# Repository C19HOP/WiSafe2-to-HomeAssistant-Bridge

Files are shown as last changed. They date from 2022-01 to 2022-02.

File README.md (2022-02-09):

# WiSafe2-to-HA Bridge readme

## Quick Links
- [Arduino Sketch](https://github.com/C19HOP/WiSafe2-to-HomeAssistant-Bridge/blob/master/Arduino/FireAngelNano.ino)
- [Enclosure](https://github.com/C19HOP/WiSafe2-to-HomeAssistant-Bridge/blob/master/Enclosure/WiSafe2-to-HA-Bridge-enclosure.stl)
- [PCB (easyEDA)](https://github.com/C19HOP/WiSafe2-to-HomeAssistant-Bridge/blob/master/PCB/WiSafe2HA-bridge-PCB.json)
- [HomeAssistant Configuration](https://github.com/C19HOP/WiSafe2-to-HomeAssistant-Bridge/tree/master/HA)

## Project Background
Like some others, I have some expired Google Nest Protects, which I wanted to replace with a cheaper / more-scalable alternative. But above all, I wanted to realise a trustworthy fire/CO alarm system, which integrates with HomeAssistant.

In pursuit of this, I initially purchased FireAngel's commercial IoT solution; The 'Connected Gateway', but after a few basic tests, I found it to be a dreadfully unreliable piece of kit. In the end, I lost all faith in the Gateway and instead, I decided to build my own bridge from a donor radio module.

## Rant about the FireAngel Pro Connected Gateway
What was so bad about the gateway?...

As part of my initial testing, I removed all the alarms from my property, ran a test, and it didn't notice! 

Specifically, when I pressed the 'test' button in the App, it took a while to time-out and then eventually reported that all my alarms were 'online'. 

Even worse, after leaving the gateway completely unplugged for almost a year, the FireAngel App still tells me that one alarm is online. It also shows some obnoxious message "Monitoring the risk to your home in real time using complex algorithms… Risk is low!?!”.

I don't know what these "complex algorithms" are, but they are certainly not "real time"! The fact that they've concluded "me and my family are safe" after being offline for 9 months is very concerning.  
I'm just glad I found this out from testing, before putting any faith in the solution.

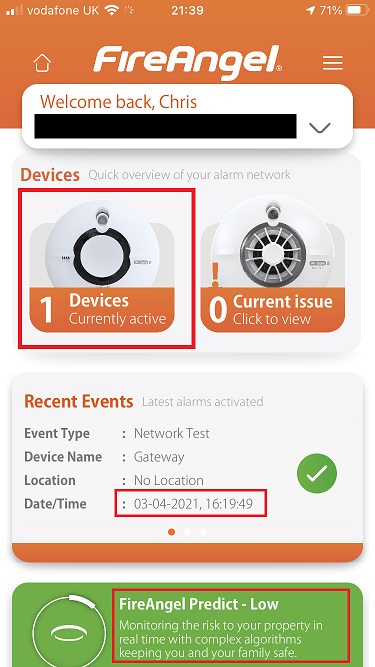
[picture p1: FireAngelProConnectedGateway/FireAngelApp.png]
App after 9 months offline


So after being bitterly disappointed with the FireAngel Gateway (and not minding if I destroyed it), my next step was to attach it to a debugger, to see exactly what it was doing (with the mindset of intercepting its comms to create a local HA integration).
I could see some JSON state changes being sent to an AWS server in Frankfurt. But I found the messages were very slow to report, and even worse was that it stopped updating locally if the internet connection went down. 

If you want to attach a serial debug logger to a Gateway yourself, then you can use a 3.3v USB-to-serial adapter, and attach GND-to-GND and TX-to-RX
 
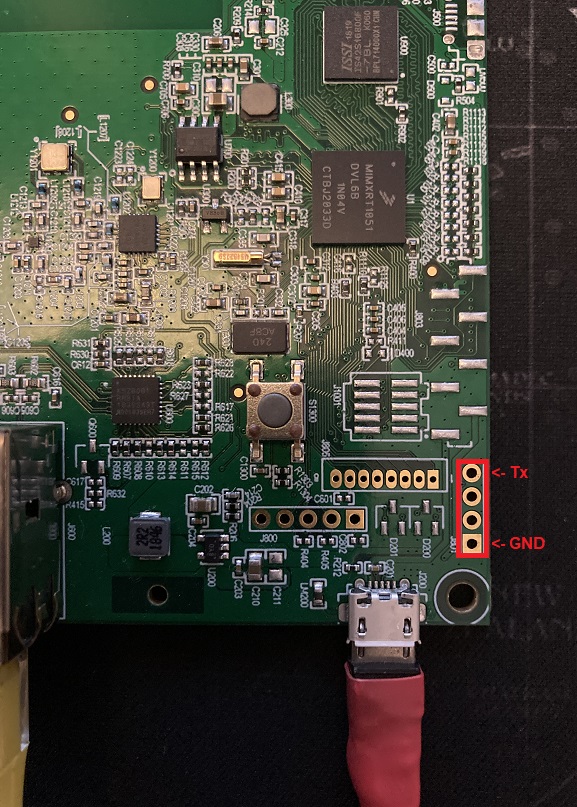
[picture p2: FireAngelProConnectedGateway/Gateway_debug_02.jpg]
Gateway Debug Pins


And if you're interested in seeing the debug log I trapped from my gateway, then you can check it out here:

[GitHub - FireAngel Pro Connected Gateway debug investigation](https://github.com/C19HOP/WiSafe2-to-HomeAssistant-Bridge/tree/master/FireAngelProConnectedGateway)

## OK. The FireAngel Gateway is bad. So what's next?

Thinking about how to capture the WiSafe2 data directly, without the FireAngel Connected Gateway, I considered using a generic 868MHz transceiver to intercept the comms. But I didn't find one for a good price. Plus, the data over-the-air is encrypted and the specification is not documented for the public anyway.
So rather than trying to communicate with the WiSafe2 network from an unsupported radio, I looked at one of the radio modules from an alarm and noted that it uses SPI to communicate with the alarm board. For me, the path of least resistance was therefore to take a radio module as a donor and use it to build my own bridge. Letting the genuine radio module deal with the encryption and network pairing.

With the radio-module on the bench, I used PulseView to inspect the signals and monitor the communication between the radio-module and the alarm. 
After spending some time testing different events and configurations , I eventually had all the information I needed to start taking to a radio-module myself.

If you're interested in the details of the SPI communication, then the link below shows what I observed:

[GitHub - WiSafeCommunicationAnalysis](https://github.com/C19HOP/WiSafe2-to-HomeAssistant-Bridge/tree/master/WiSafeCommunicationAnalysis)

Here's the radio hooked up to a logic analyser:

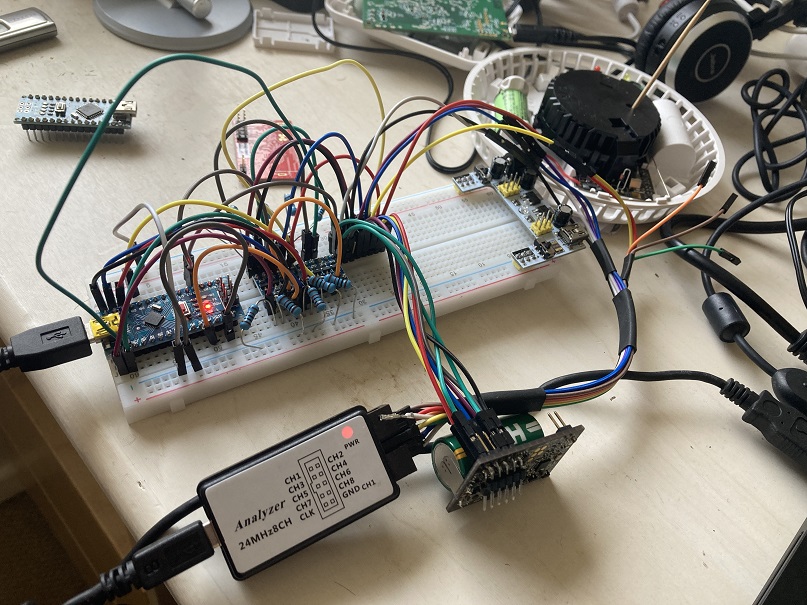
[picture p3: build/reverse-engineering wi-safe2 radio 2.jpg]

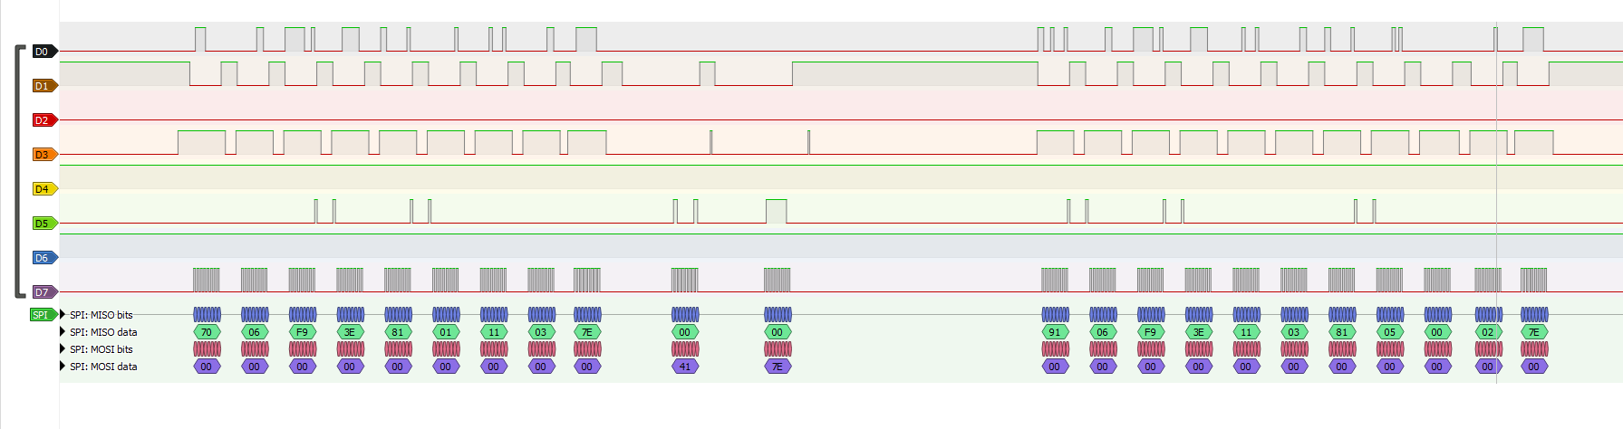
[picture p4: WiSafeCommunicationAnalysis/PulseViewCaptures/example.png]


With the the communication sussed out, the next thing was to build a driver for the radio, to allow Home Assistant to communicate with it over USB. This was done using an Arduino Nano. 

## Why a Nano?
I built this bridge using an Arduino Nano, as opposed to an ESP8266 because:
* I liked the reliability of a simple, direct USB connection (no dependency on the wifi network)
* I needed to use SPI slave mode (the radio is designed to be the master)... The ESP8266 Arduino libraries only support SPI as a master

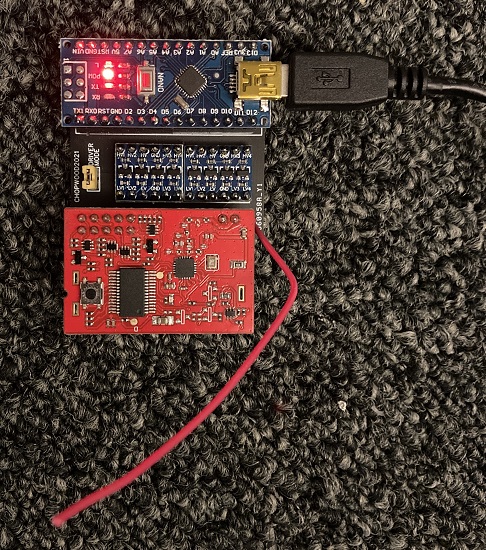
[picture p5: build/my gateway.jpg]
Prototype


## Stop!

At this point, I paused to consider the safety and reliability of a DIY approach... As should you! Safety alarms are important devices and you should not do anything which isn't approved by the manufacturer. 
The primary function of any safety alarm is to work as designed locally, and the 'smart' connection is always just a 'nice-to-have'. 

For me, all I wanted was a solution which extended the functionality of 'off-the-shelf' devices; bringing them into HomeAssistant (locally), and without modifying the hardware of the alarms in any way. 
However, before I explain how I bridged my network of FireAngel WiSafe2 alarms into HomeAssistant, you are warned that this explanation is shared purely as information. 
To be clear, there is no warranty or support, and I am not responsible if you damage anything, or if doesn't work the way you expected it to. 
If you choose to build this (or any part of it) for yourself, then you do so at your own risk.

## The WiSafe2-to-HA Bridge

So here's the explanation of how I bridged my network of FireAngel WiSafe2 alarms into HomeAssistant, using a donor WiSafe2 radio module and an Arduino Nano.

With this WiSafe2-to-HA Bridge, if it's all configured properly in HomeAssistant, you'll be able to have voice alerts in your home, telling you which room the emergency is in... Which is something FireAngel's Gateway solution doesn't offer. Yes; all the alarms beep. But they don't speak where the problem originated from.

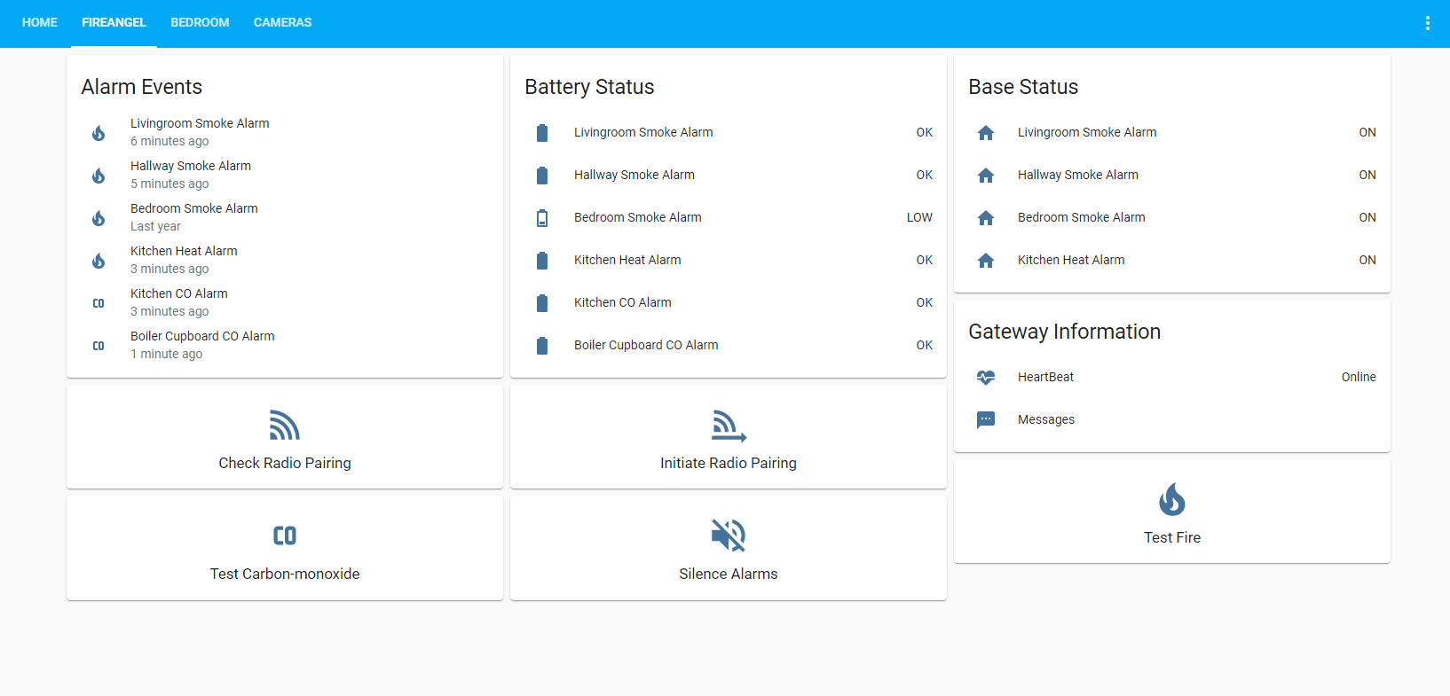
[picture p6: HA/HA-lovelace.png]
HA LoveLace


This WiSafe2-to-HA Bridge should work with any WiSafe2 alarm. But it has only been tested with the devices I actually have, which are:
* FP2620W2
* FP1720W2
* WST-630
* W2-SVP-630
* W2-CO-10X

With this project, via Home Assistant, I am able to receive notifications when:
* An alarm is tested (including the type and result)
  * heat, smoke, CO 
  * OK / Not-OK
* An emergency event occurs (including the type of event)
  * Fire
  * CO
* An alarm is removed from / attached to its base
* An alarm's battery is running low
* The other alarms are complaining about a paired (but missing) device

I can also send data back to the network, including:
* Perform a Fire Test
* Perform a CO Test
* Silence an alarm (takes a moment to propagate through the network, just like pressing the actual silence button on a physical alarm)

And I can perform some basic configuration, like check and enable network pairing mode.
The bridge also produces a heart-beat, so we can be confident that it is communicating with HA.

I highly recommend that you configure your Home Assistant instance to use Google Home / Amazon Alexa for TTS & that you have the Mobile Phone Companion App, working over the internet for remote phone notifications.

Here's what the notifications look like on my phone:
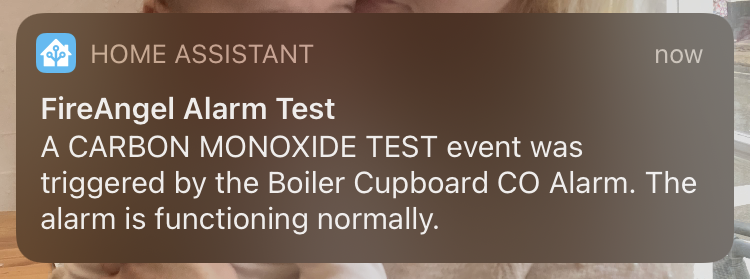
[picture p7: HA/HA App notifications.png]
HA Notification


And here's a video of the TTS notifications working through my Google Assistant speakers: 
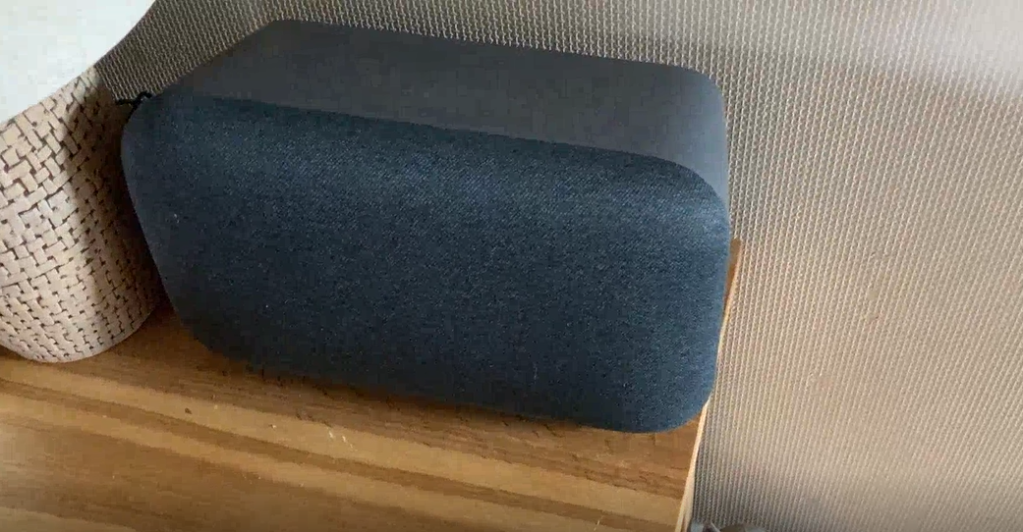
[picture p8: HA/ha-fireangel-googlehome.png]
Video of my Google Home announcing an event (https://youtu.be/Ph-9fv3ursU)


## Shopping List
To build the WiSafe2-to-HA Bridge, you'll need:
* A WiSafe2 radio module
* An Arduino Nano
* PCB
* 4ch Level Converter (x2)
* 2.54mm jumper
* 2.54mm male header (2-pins)
* Enclosure

## Obtaining the parts

### Radio
The WiSafe2 radio modules can be obtained from:
* The W2-SVP-630 strobe units can regularly be found for sale on ebay and are otherwise worthless 2nd-hand... I picked mine up for £5 :)
* Any old alarm. Perhaps you can find one which has expired, or has gone faulty.
* The radio can be bought as a stand-alone module. But expect to over-pay if buying it new.

### The Arduino Nano
Just use a regular Arduino Nano (or clone). Make sure it is 5v @ 16MHz.

### PCB
Here's a link to the PCB I made for this:
* [JSON file (for loading into easy-EDA):](https://github.com/C19HOP/WiSafe2-to-HomeAssistant-Bridge/blob/master/PCB/WiSafe2HA-bridge-PCB.json)
* [Gerber files (for ordering direct from JLCPCB, etc):](https://github.com/C19HOP/WiSafe2-to-HomeAssistant-Bridge/blob/master/PCB/Gerber_EASYEDA-WiSafe2HA-bridge-PCB.zip)

You can load the JSON into easyEDA and order some PCBs using the built-in JLCPCB ordering utility. It cost me a couple of USD, plus delivery.
Or in case it's easier for you, you can use the Gerber files to place the order yourself. 

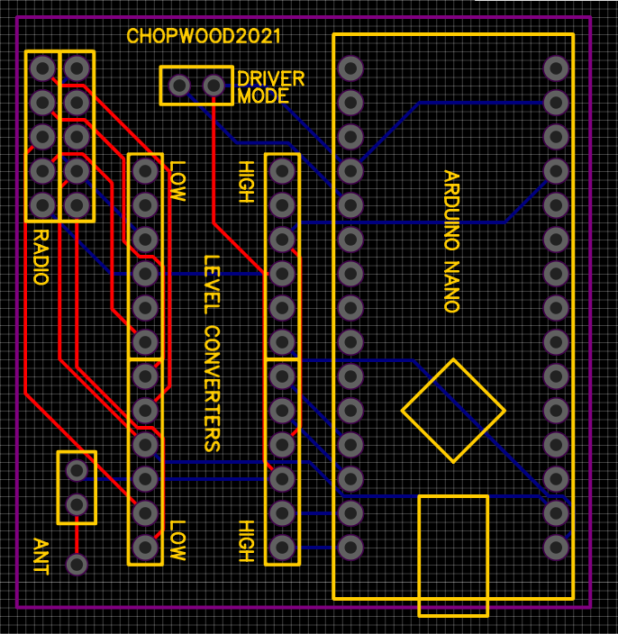
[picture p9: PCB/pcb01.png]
PCB design


### Level Converter
You need 2x 4ch level converters. Just search ebay for "4ch Logic Level Shifter Converter Module 5V to 3.3V"

### 2.54mm jumper
Rummage through your drawers. There's definitely one in there somewhere!

### 2.54mm male header
Search ebay for 2.54mm male header. You only need 2 pins for attaching the jumper to.
If this is a problem, you can always just bridge the contacts together with solder.

### Enclosure
Here's a link to the STL file for the enclosure I made: [Enclosure](https://github.com/C19HOP/WiSafe2-to-HomeAssistant-Bridge/blob/master/Enclosure/WiSafe2-to-HA-Bridge-enclosure.stl)

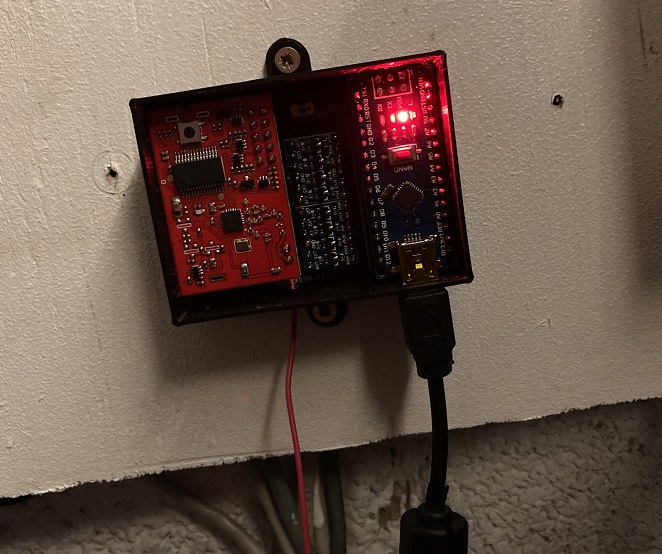
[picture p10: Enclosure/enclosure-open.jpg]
Enclosure-Open

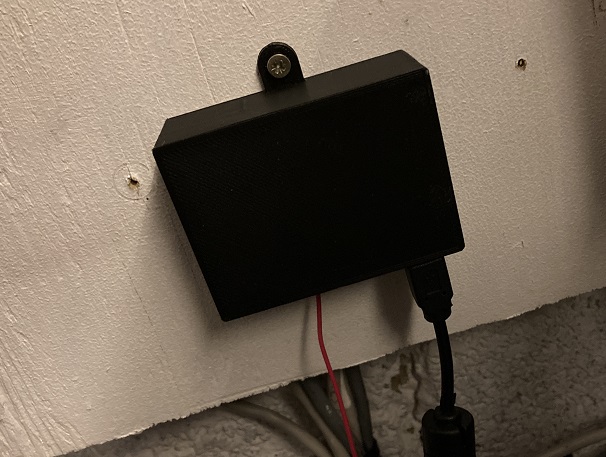
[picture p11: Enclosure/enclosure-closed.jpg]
Enclosure-Closed


## Building the project
Program the Arduino Nano, using the sketch code provided. You shouldn't need to change anything.

[Arduino Sketch](https://github.com/C19HOP/WiSafe2-to-HomeAssistant-Bridge/blob/master/Arduino/FireAngelNano.ino)

Although there are some variables declared for the 'EMBEDDED DEVICE ID' and 'MODEL', which you can change if you like. Basically, the radio thinks it's connected to an alarm. The parameters we set here define the type of alarm that the Nano will simulate.
This is used when we initiate a test from HA, or when the alarms are silenced.
The information here just needs to be unique on your network. Chances are you can just leave it all alone.

The only library dependency is the SPI library, which should be installed into the Arduino IDE by default.
If you encounter any trouble uploading the sketch, try setting the processor to "ATmega328P (old bootloader)"; I found this is nearly always required if using an Arduino Nano 'compatible'.

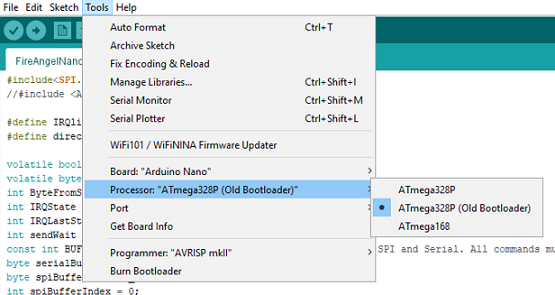
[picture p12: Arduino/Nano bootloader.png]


When you're ready to solder all the components to the PCB, you should find the layout is self-explanatory. The PCB silk-screen shows the correct way to insert the level converters and the Arduino Nano.
The WiSafe2 radio can only be soldered in one way.

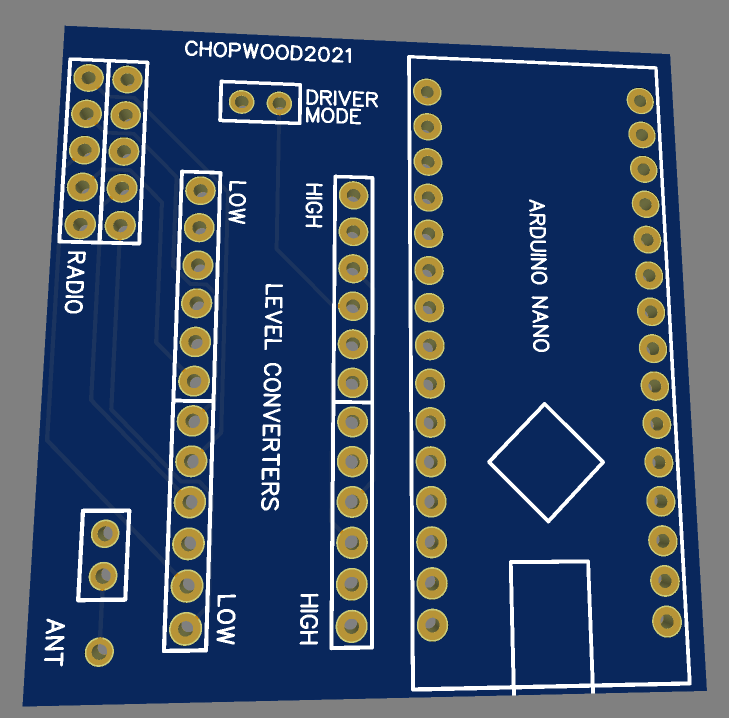
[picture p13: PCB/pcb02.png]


The antenna is just a a wire connected to the 'ANT' pin. It should be cut to 17.27cm (1/2 wavelength), or 8.64cm (1/4 wavelength).

### A note about battery powered radios
The WiSafe2 Radio modules found in alarms are powered by a built-in battery. Whereas the modules from the Strobe units are powered from the device. 
From what I have seen, radios with a red PCB are device-powered (without a battery) and radios with a black PCB are battery powered.

Optional: If your radio has a battery, you can remove it and power the radio from the Arduino. Powered by the battery, the radio has a finite life, as the battery is not rechargeable, so better to remove the battery if you can. Removing the battery is also required if you want to use the 3D-printed enclosure I provide.

If you do remove the battery from a radio which was originally battery powered, you'll need to bridge the 3.3v pin to the battery +ve terminal. See these images:

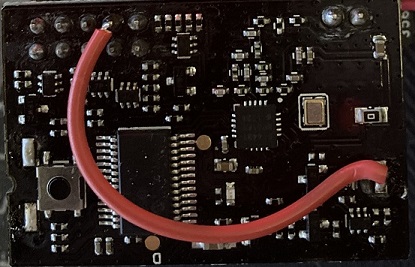
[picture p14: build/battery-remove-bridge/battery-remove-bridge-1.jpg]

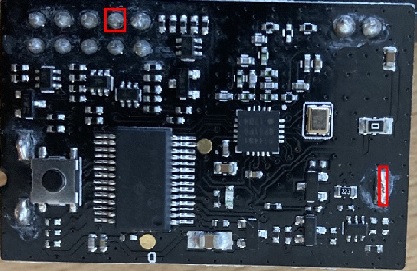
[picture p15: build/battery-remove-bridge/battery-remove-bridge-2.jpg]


## Configuring the hardware
There is a jumper which toggles the driver mode. For normal operation with HomeAssistant, the jumper needs to be on.

If you want to receive raw WiSafe2 hex data from the alarm network, for the purpose of further development (to add support for other alarms or new functions, etc. or to use this bridge with something other than HA) then you can remove the jumper. After removing the jumper, the bridge driver will send/receive raw hex data, instead of JSON formatted messages and preset CMDs. 

## Setting the bridge up in HomeAssistant
You'll be plugging the Arduino Nano into your HA server via USB. If it's the only USB-to-Serial device attached, it will show up as /dev/ttyUSB0
If you have more USB-to-serial devices attached, it could be /dev/ttyUSB1, etc. You can check this in your HomeAssistant's Hardware Page.
[http://your-ha-ip:8123/hassio/system](http://your-ha-ip:8123/hassio/system)

Then click the '⋮' icon, and then 'Hardware'

I'll assume you're using /dev/ttyUSB0 for the example configuration.

The following config is done inside the HA configuration.yaml file.
Note: Whilst this HA configuration (yaml) works fine for me, I'm sure the HA yaml gurus amongst you will be able to improve/optimise this configuration significantly.
Please feel free to contribute any improvements and optimisations to these HA configuration files if that's your thing.

First, we'll adjust the recorder. The heartbeat of the bridge updates every 25 seconds or so. It does not seem logical to have HomeAssistant record the history of the heartbeat. We can disable entity recording by adding this:

 ```yaml
recorder:
  exclude:
    entity_globs: 
      - sensor.fireangeldata   
 ```

The input from the bridge is read by a sensor template. This takes the serial data and makes individual sensors out of it, which we can use inside HA.

Here we create the sensor template, with the first two sensors; 'heartbeat' and 'messages'.
Below the 'messages' sensor, I've included 3 example alarms; Smoke, Heat and CO.
Using these 3 examples, hopefully you can see how you could add as many alarms as you need to.

We just give each alarm a name, so we can identify it in HA.
And we set the ID of each alarm, so we can identify it from the WiSafe2 network (the id is the hex number, used several times in each sensor). I'll explain how to get the IDs of your alarms shortly.

At the end of this code-block, you'll see 'PSEUDO FIRMWARE ALARM'.
This matches the 'Embedded Device ID', found in the Arduino Firmware. It's the ID the Arduino presents to the WiSafe2 network when it is performing a test or silence command.
If you haven't changed the address in the Arduino firmware, then you can just leave it alone here too.

 ```yaml
#-------------------------
#FireAngel Template Sensor
#-------------------------
sensor:
  - platform: serial
    name: fireangeldata
    serial_port: /dev/ttyUSB0
    baudrate: 115200       
  - platform: template
    sensors:

      #-------------------------
      #HeartBeat 
      #Sets state to Online / Offline, based on heartbeat messages
	  #-------------------------
      fireangel_radio_heartbeat:
        friendly_name: 'HeartBeat'
        icon_template: mdi:heart-pulse
        value_template: >
          {% if states.sensor.fireangeldata.state !='unknown' and (now() - states.sensor.fireangeldata.last_changed).total_seconds() < 125 %}
          Online
          {% else %}
          Offline!
          {% endif %}

      #-------------------------
	  #Messages
      #Handles messages from the radio to the user
	  #-------------------------
      fireangel_radio_messages:
        friendly_name: 'Messages'
        icon_template: mdi:message-processing
        value_template: >          
          {% if not '{' in states.sensor.fireangeldata.state %}
          {{states.sensor.fireangeldata.state}}
          {% endif %}
          
      #-----------------------------------    
      #2d8d01
	  #Bedroom Smoke Alarm
      #-----------------------------------  
      #EVENT
      fireangel_event_2d8d01: 
        unique_id: 'fireangel_event_2d8d01'
        friendly_name: 'Bedroom Smoke Alarm'
        icon_template: mdi:fire
        value_template: >
          {% if states.sensor.fireangeldata.attributes.device=='2d8d01'.upper() %}
          {{ states.sensor.fireangeldata.attributes.event }}
          {% elif 'MISSING' in states.sensor.fireangel_event_2d8d01.state %}
          {{ states.sensor.fireangel_event_2d8d01.state }}
          {% elif states.sensor.fireangeldata.attributes.event=='SILENCE' %}
          {{ states.sensor.fireangeldata.attributes.event }}
          {% elif 'EMERGENCY' in states.sensor.fireangel_event_2d8d01.state %}
          {{ states.sensor.fireangel_event_2d8d01.state }}
          {% endif %}
      #BATTERY
      fireangel_battery_2d8d01:
        unique_id: 'fireangel_battery_2d8d01'
        friendly_name: 'Bedroom Smoke Alarm'
        icon_template: >
          {% if states.sensor.fireangel_battery_2d8d01.state=='OK' %}
          {{'mdi:battery'}}
          {% elif states.sensor.fireangel_battery_2d8d01.state=='unknown' %}
          {{'mdi:battery-unknown'}}
          {% else %}
          {{'mdi:battery-low'}}
          {% endif %}       
        value_template: >
          {% if states.sensor.fireangeldata.attributes.device=='2d8d01'.upper() and states.sensor.fireangeldata.attributes.battery is defined %}
          {{ states.sensor.fireangeldata.attributes.battery }}
          {% else %}
          {{ states.sensor.fireangel_battery_2d8d01.state }}
          {% endif %}
      #BASE
      fireangel_onbase_2d8d01:
        unique_id: 'fireangel_onbase_2d8d01'
        friendly_name: 'Bedroom Smoke Alarm'
        icon_template: >
          {% if states.sensor.fireangel_onbase_2d8d01.state=='ON' %}
          {{'mdi:home'}}
          {% elif states.sensor.fireangel_onbase_2d8d01.state=='unknown' %}
          {{'mdi:help-circle'}}
          {% else %}
          {{'mdi:alert-circle'}}
          {% endif %}       
        value_template: >
          {% if states.sensor.fireangeldata.attributes.device=='2d8d01'.upper() %}
          {{ states.sensor.fireangeldata.attributes.base }}
          {% else %}
          {{ states.sensor.fireangel_onbase_2d8d01.state }}
          {% endif %}
          
      #-----------------------------------  
      #a76f18
	  #Kitchen Heat Alarm
      #-----------------------------------  
      #EVENT
      fireangel_event_a76f18: 
        unique_id: 'fireangel_event_a76f18'
        friendly_name: 'Kitchen Heat Alarm'
        icon_template: mdi:fire
        value_template: >
          {% if states.sensor.fireangeldata.attributes.device=='a76f18'.upper() %}
          {{ states.sensor.fireangeldata.attributes.event }}
          {% elif 'MISSING' in states.sensor.fireangel_event_a76f18.state %}
          {{ states.sensor.fireangel_event_a76f18.state }}
          {% elif states.sensor.fireangeldata.attributes.event=='SILENCE' %}
          {{ states.sensor.fireangeldata.attributes.event }}
          {% elif 'EMERGENCY' in states.sensor.fireangel_event_a76f18.state %}
          {{ states.sensor.fireangel_event_a76f18.state }}
          {% endif %}
      #BATTERY
      fireangel_battery_a76f18:
        unique_id: 'fireangel_battery_a76f18'
        friendly_name: 'Kitchen Heat Alarm'
        icon_template: >
          {% if states.sensor.fireangel_battery_a76f18.state=='OK' %}
          {{'mdi:battery'}}
          {% elif states.sensor.fireangel_battery_a76f18.state=='unknown' %}
          {{'mdi:battery-unknown'}}
          {% else %}
          {{'mdi:battery-low'}}
          {% endif %}       
        value_template: >
          {% if states.sensor.fireangeldata.attributes.device=='a76f18'.upper() and states.sensor.fireangeldata.attributes.battery is defined %}
          {{ states.sensor.fireangeldata.attributes.battery }}
          {% else %}
          {{ states.sensor.fireangel_battery_a76f18.state }}
          {% endif %}
      #BASE
      fireangel_onbase_a76f18:
        unique_id: 'fireangel_onbase_a76f18'
        friendly_name: 'Kitchen Heat Alarm'
        icon_template: >
          {% if states.sensor.fireangel_onbase_a76f18.state=='ON' %}
          {{'mdi:home'}}
          {% elif states.sensor.fireangel_onbase_a76f18.state=='unknown' %}
          {{'mdi:help-circle'}}
          {% else %}
          {{'mdi:alert-circle'}}
          {% endif %}       
        value_template: >
          {% if states.sensor.fireangeldata.attributes.device=='a76f18'.upper() %}
          {{ states.sensor.fireangeldata.attributes.base }}
          {% else %}
          {{ states.sensor.fireangel_onbase_a76f18.state }}
          {% endif %}

      #-----------------------------------  
      #ad8003
	  #Kitchen CO Alarm
      #-----------------------------------  
      #EVENT
      fireangel_event_ad8003: 
        unique_id: 'fireangel_event_ad8003'
        friendly_name: 'Kitchen CO Alarm'
        icon_template: mdi:molecule-co
        value_template: >
          {% if states.sensor.fireangeldata.attributes.device=='ad8003'.upper() %}
          {{ states.sensor.fireangeldata.attributes.event }}
          {% elif 'MISSING' in states.sensor.fireangel_event_ad8003.state %}
          {{ states.sensor.fireangel_event_ad8003.state }}
          {% elif states.sensor.fireangeldata.attributes.event=='SILENCE' %}
          {{ states.sensor.fireangeldata.attributes.event }}
          {% elif 'EMERGENCY' in states.sensor.fireangel_event_ad8003.state %}
          {{ states.sensor.fireangel_event_ad8003.state }}
          {% endif %}
      #BATTERY
      fireangel_battery_ad8003:
        unique_id: 'fireangel_battery_ad8003'
        friendly_name: 'Kitchen CO Alarm'
        icon_template: >
          {% if states.sensor.fireangel_battery_ad8003.state=='OK' %}
          {{'mdi:battery'}}
          {% elif states.sensor.fireangel_battery_ad8003.state=='unknown' %}
          {{'mdi:battery-unknown'}}
          {% else %}
          {{'mdi:battery-low'}}
          {% endif %}       
        value_template: >
          {% if states.sensor.fireangeldata.attributes.device=='ad8003'.upper() and states.sensor.fireangeldata.attributes.battery is defined %}
          {{ states.sensor.fireangeldata.attributes.battery }}
          {% else %}
          {{ states.sensor.fireangel_battery_ad8003.state }}
          {% endif %}   

	  #-----------------------------------        
      #a5b813
	  #PSEUDO FIRMWARE ALARM
	  #-----------------------------------     
	  #Used when HomeAssistant sends out a message to the WiSafe2 network (such as test or silence).
	  #This ID (a5b813) matches the default 'Device ID' configured in Arduino Firmware.
	  #If you change the ID in the Arduino code, make sure it matches here.
      #-----------------------------------  
      #EVENT
      fireangel_event_a5b813: 
        unique_id: 'fireangel_event_a5b813'
        friendly_name: 'Built in Test Function'
        value_template: >
          {% if states.sensor.fireangeldata.attributes.device=='a5b813'.upper() %}
          {{ states.sensor.fireangeldata.attributes.event }}
          {% endif %}      
 ```

We can also send commands to the bridge to perform actions. To enable this, you can add this configuration:

 ```yaml
#---------------------------------------------------------
#FireAngel shell commands (used to send data to the alarms)
#---------------------------------------------------------
shell_command:
   fireangel_test_co: /bin/bash -c "echo -e -n "1~" > /dev/ttyUSB0"
   fireangel_test_smoke: /bin/bash -c "echo -e -n "2~" > /dev/ttyUSB0"
   fireangel_test_all: /bin/bash -c "echo -e -n "3~" > /dev/ttyUSB0"
   fireangel_emergency_co: /bin/bash -c "echo -e -n "4~" > /dev/ttyUSB0"
   fireangel_emergency_smoke: /bin/bash -c "echo -e -n "5~" > /dev/ttyUSB0" 
   fireangel_silence_co: /bin/bash -c "echo -e -n "6~" > /dev/ttyUSB0"    
   fireangel_silence_smoke: /bin/bash -c "echo -e -n "7~" > /dev/ttyUSB0"    
   fireangel_get_pairing: /bin/bash -c "echo -e -n "8~" > /dev/ttyUSB0"
   fireangel_start_pairing: /bin/bash -c "echo -e -n "9~" > /dev/ttyUSB0"
 ```   

Now you can start adding some of those entities to your dashboard.

Here's my lovelace configuration. In case you want to borrow anything from it:

 ```yaml
  - title: FireAngel
    path: fireangel
    panel: false
    theme: ''
    badges: []
    cards:
      - type: entities
        entities:
          - entity: sensor.fireangel_event_13f43e
            secondary_info: last-updated
          - entity: sensor.fireangel_event_06f93e
            secondary_info: last-updated
          - entity: sensor.fireangel_event_2d8d01
            secondary_info: last-updated
          - entity: sensor.fireangel_event_a76f18
            secondary_info: last-changed
          - entity: sensor.fireangel_event_ad8003
            secondary_info: last-changed
          - entity: sensor.fireangel_event_11ce01
            secondary_info: last-updated
        title: Alarm Events
        show_header_toggle: true
        state_color: false
      - type: entities
        entities:
          - entity: sensor.fireangel_battery_13f43e
          - entity: sensor.fireangel_battery_06f93e
          - entity: sensor.fireangel_battery_2d8d01
          - entity: sensor.fireangel_battery_a76f18
          - entity: sensor.fireangel_battery_ad8003
          - entity: sensor.fireangel_battery_11ce01
        title: Battery Status
      - type: entities
        entities:
          - entity: sensor.fireangel_onbase_13f43e
          - entity: sensor.fireangel_onbase_06f93e
          - entity: sensor.fireangel_onbase_2d8d01
          - entity: sensor.fireangel_onbase_a76f18
        show_header_toggle: true
        state_color: false
        title: Base Status
      - type: entities
        entities:
          - entity: sensor.fireangel_radio_heartbeat
          - entity: sensor.fireangel_radio_messages
          - entity: sensor.fireangeldata
        title: Gateway Information
        state_color: false
      - name: Check Radio Pairing
        show_icon: true
        show_name: true
        tap_action:
          action: call-service
          service: shell_command.fireangel_get_pairing
        type: button
        icon: mdi:signal-variant
        show_state: false
        icon_height: 50px
      - name: Initiate Radio Pairing
        show_icon: true
        show_name: true
        tap_action:
          action: call-service
          service: shell_command.fireangel_start_pairing
        type: button
        icon: mdi:signal-distance-variant
        show_state: true
        icon_height: 50px
      - name: Test Fire
        show_icon: true
        show_name: true
        tap_action:
          action: call-service
          service: shell_command.fireangel_test_smoke
        type: button
        icon: mdi:fire
        show_state: false
        icon_height: 50px
      - name: Test Carbon-monoxide
        show_icon: true
        show_name: true
        tap_action:
          action: call-service
          service: shell_command.fireangel_test_co
        type: button
        icon: mdi:molecule-co
        show_state: false
        icon_height: 50px
      - name: Silence Alarms
        show_icon: true
        show_name: true
        tap_action:
          action: call-service
          service: shell_command.fireangel_silence_smoke
        type: button
        icon: mdi:volume-off
        show_state: false
        icon_height: 50px
 ```

At this point, you probably want to make sure that you at least configure an entities-card on your dashboard called 'Gateway Information' and include: 
* sensor.fireangel_radio_heartbeat 
* sensor.fireangel_radio_messages
* sensor.fireangeldata

If the bridge is communicating with HA, you should see that the heartbeat reports 'online'.
If it isn't working, check the USB connection and configuration.

Next, add yourself some buttons for each of the shell commands you're interested in.
The buttons just call services. e.g. service shell_command.fireangel_start_pairing
Again, see my lovelace configuration if you need examples.

Now you'll want to pair your bridge with your WiSafe network.
Depending where you got your radio from, it may or may not be paired already. 

If you used a new (or reset) radio, you can place the bridge into pairing mode, by pressing the button you created on the dashboard for pairing (fireangel_start_pairing).
Once in pairing mode, press the physical button one one of your alarms (as normal). The messages sensor will show the result.

If you find the network is already paired (because your radio module is 2nd hand), then you should reset it with a double push of the physical button on the back of the radio.
Google "FireAngel unlearn instructions" if you're not sure.
Then, use the 'Check Radio Pairing' dashboard button and observe the message to confirm that the radio is unpaired. You can proceed to pair with your network via HomeAssistant, as previously described.

At this point, when you test any alarm in your network, 'sensor.fireangeldata' will show a JSON string, which starts with the ID of the alarm. Take note of this ID to create the sensors you need for each alarm, based on my sample configuration.

It should just be a case of taking my example, and using search/replace with your alarm ID.

Note: Use lower-case when using the ID in the HA configuration file.

After adding your sensors and buttons, you're pretty much done.

## Value Add
For the full experience, I recommend making sure you have TTS (Google/Alexa) and Mobile Phone notifications setup and working. I won't go into detail here, as this is just general HomeAssistant stuff, and not specific to this project. 
But I'll quickly share the configuration I use for Google wavenet:

 ```yaml
tts:
  - platform: google_cloud
    base_url: http://192.168.0.200:8123
    key_file: googlecloud.json
    voice: en-GB-Wavenet-B
    encoding: linear16
    speed: 0.9
    pitch: -1.0
 ```
 
And for mobile Phone notifications:

 ```yaml
notify:
  - platform: group
    name: all_mobile_app_devices
    services:
      - service: mobile_app_iphone_1
      - service: mobile_app_iphone_2
 ```

With that, I use these automations (automations.yaml) to trigger alerts and notifications.

I receive notifications if the gateway goes offline, as well as when any alarm event occurs.
I also have the events configured as 'critical', so that my phone will make a sound, even if it is on silent.

 ```yaml
- id: '1620428541168'
  alias: FireAngel Test Fail Notifications
  description: FireAngel Test Fail Notifications
  trigger:
  - platform: state
    entity_id: sensor.fireangel_event_13f43e
  - platform: state
    entity_id: sensor.fireangel_event_2d8d01
  - platform: state
    entity_id: sensor.fireangel_event_06f93e
  - platform: state
    entity_id: sensor.fireangel_event_601a03
  - platform: state
    entity_id: sensor.fireangel_event_11ce01
  - platform: state
    entity_id: sensor.fireangel_event_a76f18
  - platform: state
    entity_id: sensor.fireangel_event_ad8003
  condition:
  - condition: template
    value_template: '{{ ''TEST'' in trigger.to_state.state }}'
  - condition: template
    value_template: '{{ states.sensor.fireangeldata.attributes.result==''FAIL''}}'
  action:
  - data_template:
      data:
        apns_headers:
          apns-collapse-id: fireangel-test-notification
      message: A {{ trigger.to_state.state }} event was triggered by the {{ trigger.to_state.attributes.friendly_name}}.
        There is a fault with the alarm! Check or replace it as necessary. See the
        user manual for full details.
      title: FireAngel Alarm Test
    service: notify.all_mobile_app_devices
  - service: tts.google_cloud_say
    data:
      entity_id: media_player.broadcast_group
      message: A {{ trigger.to_state.state }} event was triggered by the {{ trigger.to_state.attributes.friendly_name}}.
        There is a fault with the alarm. Check or replace it as necessary.
  mode: single
- id: '1620428541169'
  alias: FireAngel Test Pass Notifications
  description: FireAngel Test Pass Notifications
  trigger:
  - platform: state
    entity_id: sensor.fireangel_event_13f43e
  - platform: state
    entity_id: sensor.fireangel_event_2d8d01
  - platform: state
    entity_id: sensor.fireangel_event_06f93e
  - platform: state
    entity_id: sensor.fireangel_event_601a03
  - platform: state
    entity_id: sensor.fireangel_event_11ce01
  - platform: state
    entity_id: sensor.fireangel_event_a5b813
  - platform: state
    entity_id: sensor.fireangel_event_a76f18
  - platform: state
    entity_id: sensor.fireangel_event_ad8003
  condition:
  - condition: template
    value_template: '{{ ''TEST'' in trigger.to_state.state }}'
  - condition: template
    value_template: '{{ states.sensor.fireangeldata.attributes.result==''PASS''}}'
  action:
  - data_template:
      data:
        apns_headers:
          apns-collapse-id: fireangel-test-notification
      message: A {{ trigger.to_state.state }} event was triggered by the {{ trigger.to_state.attributes.friendly_name}}.
        The alarm is functioning normally.
      title: FireAngel Alarm Test
    service: notify.all_mobile_app_devices
  - service: tts.google_cloud_say
    data:
      entity_id: media_player.broadcast_group
      message: A {{ trigger.to_state.state }} event was triggered by the {{ trigger.to_state.attributes.friendly_name}}.
        This is only a test. The alarm is functioning normally.
  mode: single
- id: '1620428541170'
  alias: FireAngel Base Notifications
  description: FireAngel Base Notifications
  trigger:
  - platform: state
    entity_id: sensor.fireangel_onbase_13f43e
    to: 'OFF'
    for: '1'
  - platform: state
    entity_id: sensor.fireangel_onbase_2d8d01
    to: 'OFF'
    for: '1'
  - platform: state
    entity_id: sensor.fireangel_onbase_06f93e
    to: 'OFF'
    for: '1'
  - platform: state
    entity_id: sensor.fireangel_onbase_a76f18
    to: 'OFF'
    for: '1'
  condition: []
  action:
  - data_template:
      data:
        apns_headers:
          apns-collapse-id: fireangel-off-base-notification
      message: Warning! The {{ trigger.to_state.attributes.friendly_name }} was removed
        from its base
      title: FireAngel Alarm Off Base
    service: notify.all_mobile_app_devices
  - service: tts.google_cloud_say
    data:
      entity_id: media_player.broadcast_group
      message: Warning! The {{ trigger.to_state.attributes.friendly_name }} was removed
        from its base
  mode: single
- id: '1620428541171'
  alias: FireAngel Emergency Notifications
  description: FireAngel Emergency Notifications
  trigger:
  - platform: state
    entity_id: sensor.fireangel_event_13f43e
  - platform: state
    entity_id: sensor.fireangel_event_2d8d01
  - platform: state
    entity_id: sensor.fireangel_event_06f93e
  - platform: state
    entity_id: sensor.fireangel_event_601a03
  - platform: state
    entity_id: sensor.fireangel_event_11ce01
  - platform: state
    entity_id: sensor.fireangel_event_a5b813
  - platform: state
    entity_id: sensor.fireangel_event_a76f18
  - platform: state
    entity_id: sensor.fireangel_event_ad8003
  condition:
  - condition: template
    value_template: '{{ ''EMERGENCY'' in trigger.to_state.state }}'
  action:
  - data_template:
      data:
        push:
          sound:
            name: default
            critical: 1
            volume: 1.0
      message: WARNING! A {{ trigger.to_state.state }} has been reported by the {{
        trigger.to_state.attributes.friendly_name}}. Take action now!
      title: FireAngel Alarm Emergency
    service: notify.all_mobile_app_devices
  - service: tts.google_cloud_say
    data:
      entity_id: media_player.broadcast_group
      message: WARNING! WARNING! A {{ trigger.to_state.state }} has been reported
        by the {{ trigger.to_state.attributes.friendly_name}}. Take action now! This
        is not a test. Repeat. A {{ trigger.to_state.state }} has been reported by
        the {{ trigger.to_state.attributes.friendly_name}}. Take action now! This
        is not a test.
  mode: single
- id: '1620428541172'
  alias: FireAngel Offline Notifications
  description: FireAngel Offline Notifications
  trigger:
  - platform: state
    entity_id: sensor.fireangel_radio_heartbeat
    to: Offline!
    for: '35'
  condition: []
  action:
  - data_template:
      data:
        push:
          sound:
            name: default
            critical: 1
            volume: 1.0
      message: WARNING! The FireAngel Gateway is Offline
      title: FireAngel Gateway Offline
    service: notify.all_mobile_app_devices
  mode: single
- id: '1620428541173'
  alias: FireAngel Missing Notifications
  description: ''
  trigger:
  - platform: state
    entity_id: sensor.fireangel_event_13f43e
    to: MISSING
    for: '1'
  - platform: state
    entity_id: sensor.fireangel_event_2d8d01
    to: MISSING
    for: '1'
  - platform: state
    entity_id: sensor.fireangel_event_06f93e
    to: MISSING
    for: '1'
  - platform: state
    entity_id: sensor.fireangel_event_601a03
    to: MISSING
    for: '1'
  - platform: state
    entity_id: sensor.fireangel_event_11ce01
    to: MISSING
    for: '1'
  - platform: state
    entity_id: sensor.fireangel_event_a76f18
    to: MISSING
    for: '1'
  - platform: state
    entity_id: sensor.fireangel_event_ad8003
    to: MISSING
    for: '1'
  condition: []
  action:
  - data_template:
      data:
        apns_headers:
          apns-collapse-id: fireangel-missing-notification
      message: Warning! The {{ trigger.to_state.attributes.friendly_name }} has been
        reported as missing by other alarms in the network
      title: FireAngel Alarm Off Base
    service: notify.all_mobile_app_devices
  - service: tts.google_cloud_say
    data:
      entity_id: media_player.broadcast_group
      message: Warning! The {{ trigger.to_state.attributes.friendly_name }} has been
        reported as missing by other alarms in the network 
 ```

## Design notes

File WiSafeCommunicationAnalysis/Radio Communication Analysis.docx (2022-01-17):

Receive Data (from Radio, into Alarm)

Test Button Presses | 11 bytes | Constants: A=70, D=01

A | Test Signal | 1 byte | 70=Test

B | Device ID | 3 bytes

C | Trigger type | 1 byte | 81=fire, 41=CO, FF=Both

D | ? | 1 byte | Always 01 when first byte = 70? OR 01 when ok, 00 in error

E | Model ID | 3 bytes | ED08=connected, 1103=wst, 7803=CO, C304=Strobe

F | No idea, in this case, seems to be part of the model ID

G | Count | 1 byte | counts from 00-0F

H | End | 1 byte | Always 7E

fp2620w2 70 2D 8D 01 81 01 ED 08 07 03 7E

fp2620w2 70 2D 8D 01 81 00 ED 08 07 0E 7E (low bat error)

WST-630(a) 70 13 F4 3E 81 01 11 03 02 07 7E

WST-630(b) 70 06 F9 3E 81 01 11 03 02 0A 7E

W2-CO-10X(a) 70 11 CE 01 41 01 78 03 03 0E 7E

W2-CO-10X(b) 70 AD 80 03 41 01 78 03 15 0D 7E

W2-SVP-630 70 60 1A 03 FF 01 C3 04 09 09 7E

‎FP1720W2-R 70 A7 6F 18 82 01 11 04 14 0E 7E

On/Off Base, Low Battery Events | 10 bytes | Constants: A=71, E=02

A | Base Event | 1 byte | 71=Base Event

B | Device ID | 3 bytes

C | Model? | 2 bytes | ED08=connected, 1103=wst, 7803=CO, C304=Strobe

D | Trigger type | 1 byte | 01=OffBase, 05=OnBase bit3=0:offbase, bit3=1:onbase

Bit1+6 on=lowbat, bit1+6 off = batOK

E | ? | 1 byte | Always 02 when first byte = 71

F | Count | 1 byte | counts from 00-0F

G | End | 1 byte | Always 7E

WST-630(b) 71 06 F9 3E 11 03 01 02 0F 7E

fp2620w2 71 2D 8D 01 ED 08 47 07 0B 7E (attach / low bat error)

fp2620w2 71 2D 8D 01 ED 08 43 07 0F 7E (detach / low bat error)

71 2D 8D 01 ED 08 47 07 06 7E

W2-SVP-630 71 60 1A 03 C3 04 0F 09 0A 7E

71 60 1A 03 C3 04 07 09 06 7E – no motor

71 60 1A 03 C3 04 05 09 0D 7E
71 60 1A 03 C3 04 15 09 00 7E – no motor

Emergency Events | 11 bytes | Constants: A=50, E=02

A | Base Event | 1 byte | 50=Emergency Event

B | Device ID | 3 bytes

C | Trigger type | 1 byte | 81=fire, 41=CO, FF=Both

E | ? | 2 bytes |

F | Count | 1 byte | counts from 00-0F

G | End | 1 byte | Always 7E

WST-630(b) 50 06 F9 3E 81 02 02 06 7E

Missing Device report

D2 2A 38 41 00 EF 60 1A 03 00 00 09 40 7E

This ‘missing device report’ is part of what makes the FireAngel gateway so bad!

Other alarms in the network are expected to report if they detect an alarm is missing.

So if they all disappear, who tells the gateway that an alarm is missing!?

Transmit Data (from Alarm, into Radio)

Test Button Part1 | 9 bytes | Constants: A=70, D=01

A | Test Signal | 1 byte | 70=Test, 91 on 2nd command

B | Device ID | 3 bytes

C | Trigger type | 1 byte | 81=fire, 41=CO, FF=Both (seems to take first command)

D | ? | 1 byte | Always 01 when first byte = 70

E | Model ID | 3 bytes | ED08=connected, 1103=wst, 7803=CO, C304=Strobe

F | End | 1 byte | Always 7E

A | Reply 2 bytes | 417E=OK, 467E=retry

Test Button Part1 | 11 bytes | Constants: A=90, E=05

A | Test Signal | 1 byte | 70=Test, 91 on 2nd command

B | Device ID | 3 bytes

C | Model ID | 3 bytes | ED08=connected, 1103=wst, 7803=CO, C304=Strobe

D | Trigger type | 1 byte | 81=fire, 41=CO, FF=Both (seems to take first command)

E | ? | 1 byte | Always 05 when first byte is 91

F | No idea. Additional status flags? Battery, etc?

G | End | 1 byte | Always 7E

Tx Rx Tx

WST-630(b) 70 06 F9 3E 81 01 11 03 7E 41 7E 91 06 F9 3E 11 03 81 05 00 02 7E

WST-630(a) 70 13 F4 3E 81 01 11 03 7E 41 7E 91 13 F4 3E 11 03 81 05 00 02 7E

fp2620w2 70 2D 8D 01 81 01 ED 08 7E 41 7E 91 2D 8D 01 ED 08 81 05 00 01 7E

W2-SVP-630 70 60 1A 03 FF 01 C3 04 7E 41 7E 91 60 1A 03 C3 04 FF 05 01 01 7E

Emergency Event | 9 bytes | Constants: A=70, D=01

A | Test Signal | 1 byte | 70=Test, 91 on 2nd command

B | Device ID | 3 bytes

C | Trigger type | 1 byte | 81=fire, 41=CO, FF=Both (seems to take first command)

D | ? | 1 byte | Always 01 when first byte = 70

E | Model ID | 3 bytes | ED08=connected, 1103=wst, 7803=CO, C304=Strobe

F | End | 1 byte | Always 7E

A | Reply 2 bytes | 467E

Tx Rx

fp2620w2 50 2D 8D 01 81 00 7E 46 7E

fp2620w2 50 2D 8D 01 81 02 7E 46 7E

Silence Emergency Event

Tx Rx

fp2620w2 61 2D 8D 01 80 01 7E 46 7E

Get Pairing Status

Tx Rx

D3 03 7E D4 03 FF ?? 00 00 00 00 00 00 7E

D3 03 7E D4 03 00 00 00 00 00 00 00 00 7E

Pairing Mode (only works if radio is currently unpaired)

Tx RX Tx

D3 12 01 7E 46 7E 41 7E 91 60 1A 03 C3 04 FF 05 01 01 7E

<LED comes on solid. Now press test button on another device>

<LED flashes / goes out>

Erase Pairing (rarely works, better to use button)

Tx RX Tx

D3 19 01 00 7E 46 7E D4 10 00 00 00 00 00 00 00 00 40 7E

D3 19 50 00 7E 46 7E D4 10 8C 02 00 00 00 00 00 00 0C 7E

Arduino Requirements:

Transmit

Transmit Fire / CO Emergency

Transmit Fire / CO / Both Test

Transmit Silence Emergency

Trigger Pairing mode

Receive

Receive Fire / CO / Both Test

Receive Fire / CO Emergency

Receive On / Off Base status

Receive ID of originator

DeviceID

DeviceModel

Erroneous RX data

D2 62 6C 70 00 DF 2D 8D 01 00 00 0E 40 7E – Following W2-SVP-630 test
71 60 1A 03 C3 04 07 09 06 7E – Following W2-SVP-630 test with motor disconnected

71 60 1A 03 C3 04 05 09 0D 7E
71 60 1A 03 C3 04 15 09 00 7E – Following W2-SVP-630 test with battery disconnected

D2 62 6C 70 00 DF 2D 8D 01 00 00 0E 40 7E

D2 2A 38 41 00 EF 60 1A 03 00 00 09 40 7E

D2 2A 38 41 00 EF 60 1A 03 00 00 09 40 7E

D2 2B 37 41 00 EF 60 1A 03 00 00 09 40 7E

D2 2B 37 41 00 EF 60 1A 03 00 00 09 40 7E

D2 2A 38 41 00 EF 60 1A 03 00 00 09 40 7E

D2 2B 37 38 00 EF 60 1A 03 00 00 09 40 7E

70 2D 8D 01 81 00 ED 08 07 0E 7E

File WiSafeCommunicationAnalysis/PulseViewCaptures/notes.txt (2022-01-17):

When the alarm wants to send data to a radio, like when alarm is triggered or test button is pressed, then alarm pulls IRQ (pin8) high (normally low).
IRQ goes high, the radio (master) responds by sending _SS low and running the clock.
One byte is sent from alarm to radio, then _SS returns high.
IRQ goes low then high for the next byte.

When radio wants to transmit to alarm, like when the other alarms go off...
_SS is brought low. Clock runs and byte is sent from SDO (pin6).
_SS then returns high. Alarm seems to ACK with a pulse on IRQ (pin8).
_SS then goes low again and next byte is sent

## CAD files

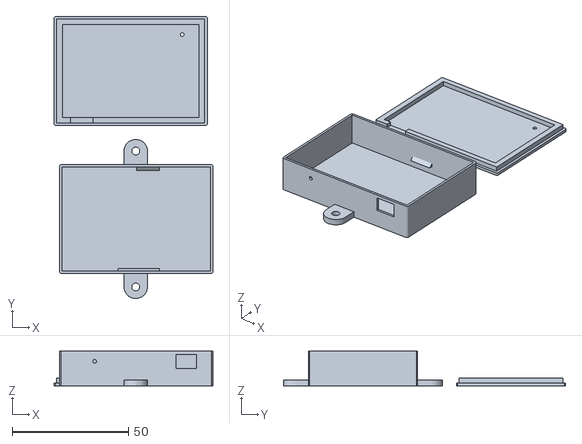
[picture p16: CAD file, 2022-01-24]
Enclosure/WiSafe2-to-HA-Bridge-enclosure.stl
68.4 x 121.5 x 15.0

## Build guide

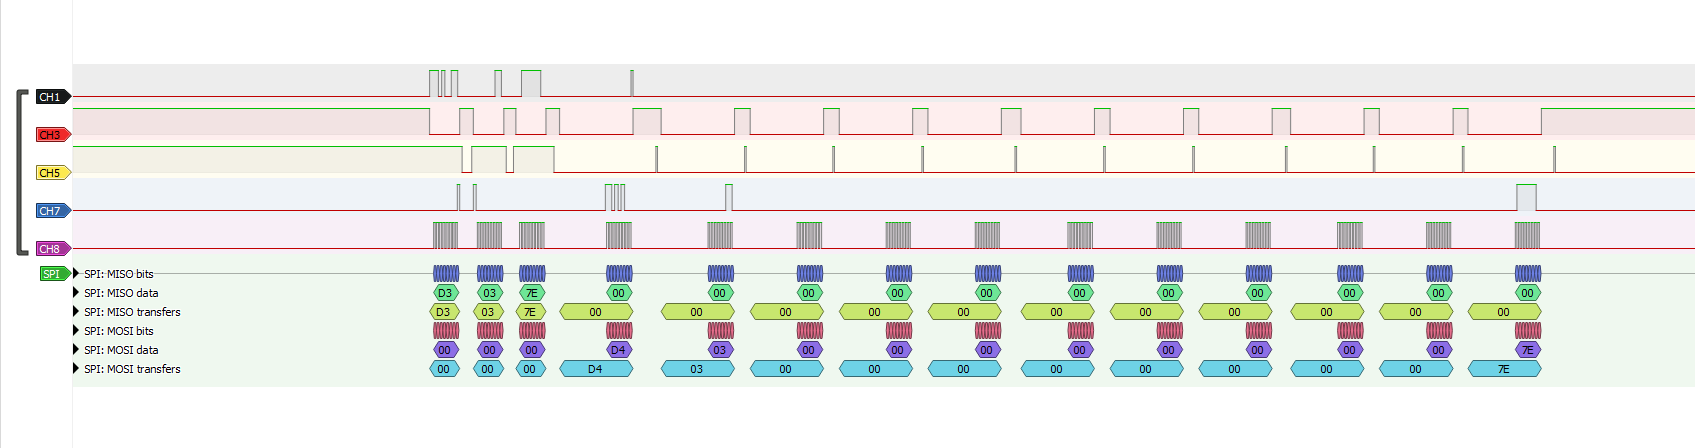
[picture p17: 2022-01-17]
WiSafeCommunicationAnalysis/PulseViewCaptures/strobe/manual de-pair.png

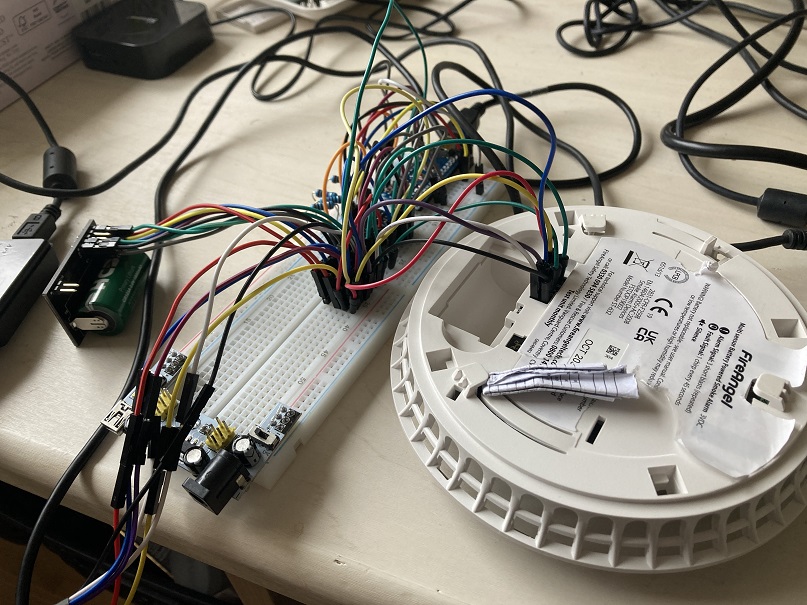
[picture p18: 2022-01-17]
build/reverse-engineering wi-safe2 radio 1.jpg

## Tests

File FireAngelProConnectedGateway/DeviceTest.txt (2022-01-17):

test
70 2d 8d 01 81 01 ed 08 07 08

Device tested message received for SID (7)

off base
71 2d 8d 01 ed 08 01 07 09 

[01;35mFault received from device 0x018d2d, model 0x08ed, flags 0x01, SID 7, seq 9

Devices

   70.974 INF LogSetOperation: [01;34mSetting reported property 'flt' (20000064) on device id=0000000000018d2d to false[00m
   70.987 INF LogSetOperation: [01;34mSetting create property 'mute' (2000000f) on device id=0000000000018d2d to false[00m
   71.000 INF LogSetOperation: [01;34mSetting reported property 'c_fld' (20000013) on device id=0000000000018d2d to false[00m
   71.015 INF LogSetOperation: [01;34mSetting reported property 'iddev_trgrd' (2000001c) on device id=0000000000018d2d to 0[00m
   
   71.028 INF LogSetOperation: [01;34mSetting reported property 'flt' (20000064) on device id=00000000003ef906 to false[00m
   71.042 INF LogSetOperation: [01;34mSetting create property 'mute' (2000000f) on device id=00000000003ef906 to false[00m
   71.054 INF LogSetOperation: [01;34mSetting reported property 'c_fld' (20000013) on device id=00000000003ef906 to false[00m
   71.066 INF LogSetOperation: [01;34mSetting reported property 'iddev_trgrd' (2000001c) on device id=00000000003ef906 to 0[0
   0m
   71.079 INF LogSetOperation: [01;34mSetting reported property 'flt' (20000064) on device id=00000000003ef413 to false[00m
   71.092 INF LogSetOperation: [01;34mSetting create property 'mute' (2000000f) on device id=00000000003ef413 to false[00m
   71.104 INF LogSetOperation: [01;34mSetting reported property 'c_fld' (20000013) on device id=00000000003ef413 to false[00m
   71.117 INF LogSetOperation: [01;34mSetting reported property 'iddev_trgrd' (2000001c) on device id=00000000003ef413 to 0[00m
   
   71.130 INF LogSetOperation: [01;34mSetting reported property 'flt' (20000064) on device id=000000000001ce11 to false[00m
   71.144 INF LogSetOperation: [01;34mSetting create property 'mute' (2000000f) on device id=000000000001ce11 to false[00m
   71.156 INF LogSetOperation: [01;34mSetting reported property 'c_fld' (20000013) on device id=000000000001ce11 to false[00m
   71.168 INF LogSetOperation: [01;34mSetting reported property 'iddev_trgrd' (2000001c) on device id=000000000001ce11 to 0[00m

   events
  a - test button
  
 1941.695 INF LogSetOperation: [01;34mSetting reported property 'mfr' (2) on device id=0000000000018d2d to 'Sprue'[00m
 1941.697 INF LogSetOperation: [01;34mSetting reported property 'mdVal' (20000005) on device id=0000000000018d2d to 2285[00m
 1941.699 INF LogSetOperation: [01;34mSetting reported property 'model' (3) on device id=0000000000018d2d to '2285'[00m
 1941.700 INF LogSetOperation: [01;34mSetting reported property 'onln' (4) on device id=0000000000018d2d to 1[00m
 1941.703 INF LogSetOperation: [01;34mSetting reported property 'sid' (20000004) on device id=0000000000018d2d to 7[00m
 1941.705 INF LogSetOperation: [01;34mSetting reported property 'testb' (20000003) on device id=0000000000018d2d to 1617300402[00m
 
 Setting reported property 'netwk' (20000001) on device id=0000e41e0aa03420 to true

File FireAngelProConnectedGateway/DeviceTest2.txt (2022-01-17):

A - test button

1941.686 INF wisafedrv_read: ^^^^^^^^^^^^^^^^^^^^^^^^^^^^^^^^^^^^^[00m

 1941.687 INF WiSafe_RadioCommsBufferDump: <- RX Buffer @ 0x801449cc, has 10 bytes.[00m

 1941.689 INF WiSafe_RadioCommsBufferDump:       Contents: 70 2d 8d 01 81 01 ed 08 07 08 [00m

 1941.692 INF wisafedrv_read: vvvvvvvvvvvvvvvvvvvvvvvvvvvvvvvvvvvvv[00m

 1941.691 INF LogSetOperation: [01;34mSetting reported property 'ltseq' (2000000e) on device id=0000000000018d2d to 8[00m

 1941.692 INF wisafedrv_read: wisafedrv read[00m

 1941.694 INF WiSafe_DiscoveryProcessDeviceTested: [01;36mDevice tested message received for SID (7).[00m

 1941.695 INF LogSetOperation: [01;34mSetting reported property 'mfr' (2) on device id=0000000000018d2d to 'Sprue'[00m

 1941.697 INF LogSetOperation: [01;34mSetting reported property 'mdVal' (20000005) on device id=0000000000018d2d to 2285[00m

 1941.699 INF LogSetOperation: [01;34mSetting reported property 'model' (3) on device id=0000000000018d2d to '2285'[00m

 1941.700 INF LogSetOperation: [01;34mSetting reported property 'onln' (4) on device id=0000000000018d2d to 1[00m

 1941.703 INF LogSetOperation: [01;34mSetting reported property 'sid' (20000004) on device id=0000000000018d2d to 7[00m

 1941.705 INF LogSetOperation: [01;34mSetting reported property 'testb' (20000003) on device id=0000000000018d2d to 1617300402[00m

 A- off base
 
 2128.932 INF RM_MainLoop: WiSafe RM Task[00m

 2128.939 INF RM_MainLoop: [01;32mWiSafe RM Exit[00m

 2130.430 INF RM_MainLoop: WiSafe RM Task[00m

 2130.437 INF RM_MainLoop: [01;32mWiSafe RM Exit[00m

 2131.928 INF RM_MainLoop: WiSafe RM Task[00m

 2131.936 INF RM_MainLoop: [01;32mWiSafe RM Exit[00m

 2133.426 INF RM_MainLoop: WiSafe RM Task[00m

 2133.435 INF RM_MainLoop: [01;32mWiSafe RM Exit[00m

 2134.926 INF RM_MainLoop: WiSafe RM Task[00m

 2134.934 INF RM_MainLoop: [01;32mWiSafe RM Exit[00m

 2136.424 INF RM_MainLoop: WiSafe RM Task[00m

 2136.431 INF RM_MainLoop: [01;32mWiSafe RM Exit[00m

 2137.922 INF RM_MainLoop: WiSafe RM Task[00m

 2137.930 INF RM_MainLoop: [01;32mWiSafe RM Exit[00m

 2139.420 INF RM_MainLoop: WiSafe RM Task[00m

 2139.427 INF RM_MainLoop: [01;32mWiSafe RM Exit[00m

 2140.918 INF RM_MainLoop: WiSafe RM Task[00m

 2140.925 INF RM_MainLoop: [01;32mWiSafe RM Exit[00m

 2141.560 TRC Watchdog: WDT Refresh[00m

 2141.560 TRC OSAL_watchdog_refresh: [00m

 2142.416 INF RM_MainLoop: WiSafe RM Task[00m

 2142.423 INF RM_MainLoop: [01;32mWiSafe RM Exit[00m

 2143.914 INF RM_MainLoop: WiSafe RM Task[00m

 2143.921 INF RM_MainLoop: [01;32mWiSafe RM Exit[00m

 2145.412 INF RM_MainLoop: WiSafe RM Task[00m

 2145.419 INF RM_MainLoop: [01;32mWiSafe RM Exit[00m

 2146.910 INF RM_MainLoop: WiSafe RM Task[00m

 2146.917 INF RM_MainLoop: [01;32mWiSafe RM Exit[00m

 2148.408 INF RM_MainLoop: WiSafe RM Task[00m

 2148.416 INF RM_MainLoop: [01;32mWiSafe RM Exit[00m

 2149.906 INF RM_MainLoop: WiSafe RM Task[00m

 2149.913 INF RM_MainLoop: [01;32mWiSafe RM Exit[00m

 2151.404 INF RM_MainLoop: WiSafe RM Task[00m

 2151.412 INF RM_MainLoop: [01;32mWiSafe RM Exit[00m

 2152.902 INF RM_MainLoop: WiSafe RM Task[00m

 2152.909 INF RM_MainLoop: [01;32mWiSafe RM Exit[00m

 2154.400 INF RM_MainLoop: WiSafe RM Task[00m

 2154.408 INF RM_MainLoop: [01;32mWiSafe RM Exit[00m

 2155.898 INF RM_MainLoop: WiSafe RM Task[00m

 2155.907 INF writeWGqueue: xQueueRMtoWG --->success[00m

 2155.908 INF RM_MainLoop: [01;32mWiSafe RM Exit[00m

 2155.909 INF wisafedrv_read: <<< 71[00m

 2155.910 INF wisafedrv_read: <<< 2D[00m

 2155.911 INF wisafedrv_read: <<< 8D[00m

 2155.911 INF wisafedrv_read: <<< 01[00m

 2155.912 INF wisafedrv_read: <<< ED[00m

 2155.912 INF wisafedrv_read: <<< 08[00m

 2155.913 INF wisafedrv_read: <<< 01[00m

 2155.913 INF wisafedrv_read: <<< 07[00m

 2155.914 INF wisafedrv_read: <<< 09[00m

 2155.914 INF wisafedrv_read: <<< 7E[00m

 2155.915 INF wisafedrv_read: ^^^^^^^^^^^^^^^^^^^^^^^^^^^^^^^^^^^^^[00m

 2155.916 INF WiSafe_RadioCommsBufferDump: <- RX Buffer @ 0x801449cc, has 9 bytes.[00m

 2155.918 INF WiSafe_RadioCommsBufferDump:       Contents: 71 2d 8d 01 ed 08 01 07 09 [00m

 2155.920 INF wisafedrv_read: vvvvvvvvvvvvvvvvvvvvvvvvvvvvvvvvvvvvv[00m

 2155.920 INF wisafedrv_read: wisafedrv read[00m

 2155.921 INF LogSetOperation: [01;34mSetting reported property 'ltseq' (2000000e) on device id=0000000000018d2d to 9[00m

 2155.923 WAR ECOM_SendUpdateToSubscriber: [01;31mDeltas buffer is empty, nothing to do[00m

 2155.924 INF WiSafe_FaultReceived: [01;35mFault received from device 0x018d2d, model 0x08ed, flags 0x01, SID 7, seq 9.[00m

 2155.926 TRC WiSafe_FaultReceived: fault flag 0 is 1[00m

 2155.926 INF WiSafe_FaultReceived: [01;35mFault flag set for FAULT_FLAG_CALIBRATED.[00m

 2155.927 TRC SendFaultEvent: received fault active = 0, code = 90[00m

 2155.928 TRC SendFaultEvent: faultName = |flt90|[00m

 2155.929 TRC SendFaultEvent: propertyId = 536871202[00m

 2155.930 TRC WiSafe_FaultReceived: fault flag 1 is 0[00m

 2155.931 INF WiSafe_FaultReceived: [01;35mFault flag set for FAULT_FLAG_FAULTY.[00m

 2155.932 INF WiSafe_FaultReceived: faulty flag not set - clear active faults[00m

 2155.933 TRC SendFaultEvent: received fault active = 0, code = 2[00m

 2155.934 TRC SendFaultEvent: faultName = |flt02|[00m

 2155.936 TRC SendFaultEvent: propertyId = 536871114[00m

 2155.936 TRC SendFaultEvent: received fault active = 0, code = 4[00m

 2155.938 TRC SendFaultEvent: faultName = |flt04|[00m

 2155.938 TRC SendFaultEvent: propertyId = 536871116[00m

 2155.940 TRC SendFaultEvent: received fault active = 0, code = 6[00m

 2155.941 TRC SendFaultEvent: faultName = |flt06|[00m

 2155.941 TRC SendFaultEvent: propertyId = 536871118[00m

 2155.942 TRC SendFaultEvent: received fault active = 0, code = 8[00m

 2155.943 TRC SendFaultEvent: faultName = |flt08|[00m

 2155.943 TRC SendFaultEvent: propertyId = 536871120[00m

 2155.944 TRC SendFaultEvent: received fault active = 0, code = 10[00m

 2155.945 TRC SendFaultEvent: faultName = |flt10|[00m

 2155.946 TRC SendFaultEvent: propertyId = 536871122[00m

 2155.947 TRC SendFaultEvent: received fault active = 0, code = 14[00m

 2155.948 TRC SendFaultEvent: faultName = |flt14|[00m

 2155.948 TRC SendFaultEvent: propertyId = 536871126[00m

 2155.949 TRC SendFaultEvent: received fault active = 0, code = 16[00m

 2155.950 TRC SendFaultEvent: faultName = |flt16|[00m

 2155.950 TRC SendFaultEvent: propertyId = 536871128[00m

 2155.951 TRC SendFaultEvent: received fault active = 0, code = 18[00m

 2155.952 TRC SendFaultEvent: faultName = |flt18|[00m

 2155.953 TRC SendFaultEvent: propertyId = 536871130[00m

 2155.954 TRC SendFaultEvent: received fault active = 0, code = 19[00m

 2155.955 TRC SendFaultEvent: faultName = |flt19|[00m

 2155.955 TRC SendFaultEvent: propertyId = 536871131[00m

 2155.956 TRC SendFaultEvent: received fault active = 0, code = 22[00m

 2155.957 TRC SendFaultEvent: faultName = |flt22|[00m

 2155.958 TRC SendFaultEvent: propertyId = 536871134[00m

 2155.959 TRC SendFaultEvent: received fault active = 0, code = 25[00m

 2155.960 TRC SendFaultEvent: faultName = |flt25|[00m

 2155.960 TRC SendFaultEvent: propertyId = 536871137[00m

 2155.961 TRC SendFaultEvent: received fault active = 0, code = 30[00m

 2155.962 TRC SendFaultEvent: faultName = |flt30|[00m

 2155.962 TRC SendFaultEvent: propertyId = 536871142[00m

 2155.963 TRC SendFaultEvent: received fault active = 0, code = 91[00m

 2155.964 TRC SendFaultEvent: faultName = |flt91|[00m

 2155.965 TRC SendFaultEvent: propertyId = 536871203[00m

 2155.966 TRC WiSafe_FaultReceived: fault flag 2 is 0[00m

 2155.966 INF WiSafe_FaultReceived: [01;35mFault flag set for FAULT_FLAG_ON_BASE.[00m

 2155.967 TRC SendFaultEvent: received fault active = 1, code = 92[00m

 2155.968 TRC SendFaultEvent: faultName = |flt92|[00m

 2155.969 TRC SendFaultEvent: propertyId = 536871204[00m

 2155.970 TRC SendFaultEvent: propertyId = 536871304[00m

 2155.971 TRC SendFaultEvent: faultNameState = |flt92_state|[00m

 2155.972 TRC SendFaultEvent: faultNameSeq = |flt92_seq|[00m

 2155.973 TRC SendFaultEvent: faultNameTime = |flt92_time|[00m

 2155.974 INF SetPropertiesHelper: [01;34mSetting set of 3 reported properties as a group[00m

 2155.975 INF LogSetOperation: [01;34mSetting reported property 'flt92_state' (20000124) on device id=0000000000018d2d to true[00m

 2155.976 INF LogSetOperation: [01;34mSetting reported property 'flt92_seq' (20000188) on device id=0000000000018d2d to 0[00m

 2155.978 INF LogSetOperation: [01;34mSetting reported property 'flt92_time' (200001ec) on device id=0000000000018d2d to 1617300616[00m

 2155.981 TRC _STO_MessageQueueListener: Delta[00m

 2155.981 TRC _STO_OnUpdate: Writing for flt92_state, desired outOfSync=0, reportedOutOfSync=1[00m

 2155.981 TRC STO_WriteRecord: Tag:0000000000018d2d_0000_00 20000124 0000031d 00 Desired  Name:flt92_state Len:12 Val:Bool true[00m

 2155.990 TRC WiSafe_FaultReceived: fault flag 3 is 0[00m

 2155.992 INF WiSafe_FaultReceived: [01;35mFault flag set for FAULT_FLAG_SD_BATTERY_FAULT.[00m

 2155.994 TRC SendFaultEvent: received fault active = 0, code = 93[00m

 2155.996 TRC SendFaultEvent: faultName = |flt93|[00m

 2155.998 TRC SendFaultEvent: propertyId = 536871205[00m

 2156.000 TRC WiSafe_FaultReceived: fault flag 4 is 0[00m

 2156.000 INF WiSafe_FaultReceived: [01;35mFault flag set for FAULT_FLAG_AC_FAILED.[00m

 2156.002 TRC SendFaultEvent: received fault active = 0, code = 94[00m

 2156.004 TRC SendFaultEvent: faultName = |flt94|[00m

 2156.006 TRC SendFaultEvent: propertyId = 536871206[00m

 2156.008 TRC WiSafe_FaultReceived: fault flag 5 is 0[00m

 2156.008 INF WiSafe_FaultReceived: [01;35mFault flag set for FAULT_FLAG_RM_BATTERY_FAULT.[00m

 2156.010 TRC SendFaultEvent: received fault active = 0, code = 95[00m

 2156.012 TRC SendFaultEvent: faultName = |flt95|[00m

 2156.014 TRC SendFaultEvent: propertyId = 536871207[00m

 2156.016 TRC WiSafe_FaultReceived: fault flag 6 is 0[00m

 2156.018 TRC WiSafe_FaultReceived: fault flag 7 is 0[00m

 2156.051 TRC STO_CheckSizeAndConsolidate: Store size : 8700[00m

 2156.052 TRC _STO_MessageQueueListener: Delta[00m

 2156.052 TRC _STO_OnUpdate: Writing for flt92_state, desired outOfSync=0, reportedOutOfSync=1[00m

 2156.053 TRC STO_WriteRecord: Tag:0000000000018d2d_0000_00 20000124 8010031d 01 Reported Name:flt92_state Len:12 Val:Bool true[00m

 2156.122 TRC STO_CheckSizeAndConsolidate: Store size : 8750[00m

 2156.122 TRC _STO_MessageQueueListener: Delta[00m

 2156.122 TRC _STO_OnUpdate: Writing for flt92_seq, desired outOfSync=0, reportedOutOfSync=1[00m

 2156.123 TRC STO_WriteRecord: Tag:0000000000018d2d_0000_00 20000188 8010011d 00 Desired  Name:00flt92_seq Len:12 Val:U32  0[00m

 2156.190 TRC STO_CheckSizeAndConsolidate: Store size : 8800[00m

 2156.191 TRC _STO_MessageQueueListener: Delta[00m

 2156.191 TRC _STO_OnUpdate: Writing for flt92_seq, desired outOfSync=0, reportedOutOfSync=1[00m

 2156.191 TRC STO_WriteRecord: Tag:0000000000018d2d_0000_00 20000188 0000011d 01 Reported Name:00flt92_seq Len:12 Val:U32  0[00m

 2156.260 TRC STO_CheckSizeAndConsolidate: Store size : 8850[00m

 2156.260 TRC _STO_MessageQueueListener: Delta[00m

 2156.261 TRC _STO_OnUpdate: Writing for flt92_time, desired outOfSync=0, reportedOutOfSync=1[00m

 2156.261 TRC STO_WriteRecord: Tag:0000000000018d2d_0000_00 200001ec 0000061d 00 Desired  Name:0flt92_time Len:12 Val:Time 1617300616[00m

 2156.326 TRC STO_CheckSizeAndConsolidate: Store size : 8900[00m

 2156.326 TRC _STO_MessageQueueListener: Delta[00m

 2156.327 TRC _STO_OnUpdate: Writing for flt92_time, desired outOfSync=0, reportedOutOfSync=1[00m

 2156.327 TRC STO_WriteRecord: Tag:0000000000018d2d_0000_00 200001ec 0000061d 01 Reported Name:0flt92_time Len:12 Val:Time 1617300616[00m

 2156.396 TRC STO_CheckSizeAndConsolidate: Store size : 8950[00m

 2156.396 TRC _STO_MessageQueueListener: Delta[00m

 2156.396 TRC _STO_OnUpdate: Writing for flt92_state, desired outOfSync=0, reportedOutOfSync=1[00m

 2156.397 TRC STO_WriteRecord: Tag:0000000000018d2d_0000_00 20000124 8010031d 01 Reported Name:flt92_state Len:12 Val:Bool true[00m

 2156.462 TRC _STO_OnUpdate: Writing for flt92_seq, desired outOfSync=0, reportedOutOfSync=1[00m

 2156.462 TRC STO_WriteRecord: Tag:0000000000018d2d_0000_00 20000188 8010011d 01 Reported Name:00flt92_seq Len:12 Val:U32  0[00m

 2156.526 TRC _STO_OnUpdate: Writing for flt92_time, desired outOfSync=0, reportedOutOfSync=1[00m

 2156.526 TRC STO_WriteRecord: Tag:0000000000018d2d_0000_00 200001ec 8010061d 01 Reported Name:0flt92_time Len:12 Val:Time 1617300616[00m

 2156.594 TRC STO_CheckSizeAndConsolidate: Store size : 9100[00m

 2157.129 TRC AWS_SendWaitingDelta: subscriberId 1 Start buffer = 801414F4, count = 1, num properties = 3[00m

 2157.139 INF AWS_CommsChannelDeltaSend: --> 94:{"state":{"reported":{"flt92":{"state":true,"seq":0,"time":1617300616}}}, "clientToken":"-12"}[00m

 2157.398 INF RM_MainLoop: WiSafe RM Task[00m

 2157.405 INF RM_MainLoop: [01;32mWiSafe RM Exit[00m

 2158.896 INF RM_MainLoop: WiSafe RM Task[00m

 2158.903 INF RM_MainLoop: [01;32mWiSafe RM Exit[00m

 2159.388 TRC _STO_MessageQueueListener: Delta[00m

 2159.388 TRC _STO_OnUpdate: Writing for flt92_state, desired outOfSync=0, reportedOutOfSync=0[00m

 2159.388 TRC STO_WriteRecord: Tag:0000000000018d2d_0000_00 20000124 0000031c 01 Reported Name:flt92_state Len:12 Val:Bool true[00m

 2159.456 TRC STO_CheckSizeAndConsolidate: Store size : 9150[00m

 2159.457 TRC _STO_MessageQueueListener: Delta[00m

 2159.457 TRC _STO_OnUpdate: Writing for flt92_seq, desired outOfSync=0, reportedOutOfSync=0[00m

 2159.457 TRC STO_WriteRecord: Tag:0000000000018d2d_0000_00 20000188 0000011c 01 Reported Name:00flt92_seq Len:12 Val:U32  0[00m

 2159.523 TRC STO_CheckSizeAndConsolidate: Store size : 9200[00m

 2159.524 TRC _STO_MessageQueueListener: Delta[00m

 2159.524 TRC _STO_OnUpdate: Writing for flt92_time, desired outOfSync=0, reportedOutOfSync=0[00m

 2159.524 TRC STO_WriteRecord: Tag:0000000000018d2d_0000_00 200001ec 0000061c 01 Reported Name:0flt92_time Len:12 Val:Time 1617300616[00m

 2159.588 TRC STO_CheckSizeAndConsolidate: Store size : 9250[00m

 2159.992 TRC LSD_SendPropertiesByFilter_Safe: Sending UPDATE message with 1 deltas[00m

 2159.994 INF LSD_SyncLocalShadow: Sent out-of-sync deltas using 1 messages[00m

 2160.394 INF RM_MainLoop: WiSafe RM Task[00m

 2160.401 INF RM_MainLoop: [01;32mWiSafe RM Exit[00m

 2161.086 TRC AWS_SendWaitingDelta: subscriberId 1 Start buffer = 80141540, count = 1, num properties = 1[00m

 2161.091 INF AWS_CommsChannelDeltaSend: --> 64:{"state":{"reported":{"testb":1617300402}}, "clientToken":"-13"}[00m

 2161.560 TRC Watchdog: WDT Refresh[00m

 2161.560 TRC OSAL_watchdog_refresh: [00m

 2161.892 INF RM_MainLoop: WiSafe RM Task[00m

 2161.899 INF RM_MainLoop: [01;32mWiSafe RM Exit[00m

 2163.390 INF RM_MainLoop: WiSafe RM Task[00m

 2163.397 INF RM_MainLoop: [01;32mWiSafe RM Exit[00m

 2164.001 INF _PeriodicWorker: Fault buffer empty, nothing out of sync - fault processing stopping[00m

 2164.888 INF RM_MainLoop: WiSafe RM Task[00m

 2164.896 INF RM_MainLoop: [01;32mWiSafe RM Exit[00m

 2166.386 INF RM_MainLoop: WiSafe RM Task[00m

 2166.393 INF RM_MainLoop: [01;32mWiSafe RM Exit[00m

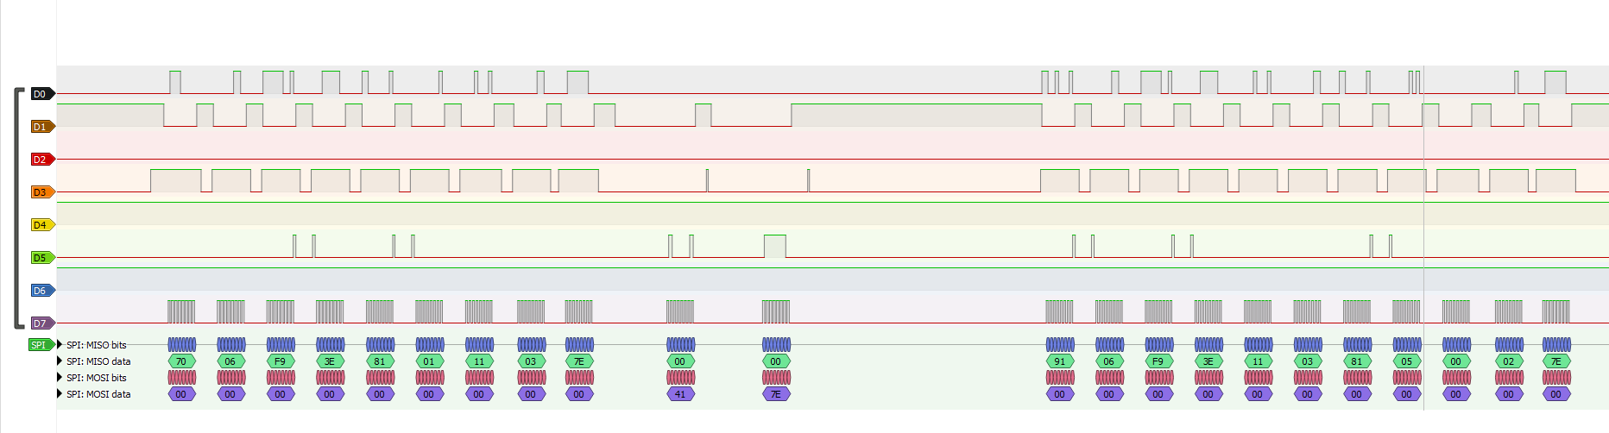
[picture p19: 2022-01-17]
WiSafeCommunicationAnalysis/PulseViewCaptures/pulseview local test button 1.png

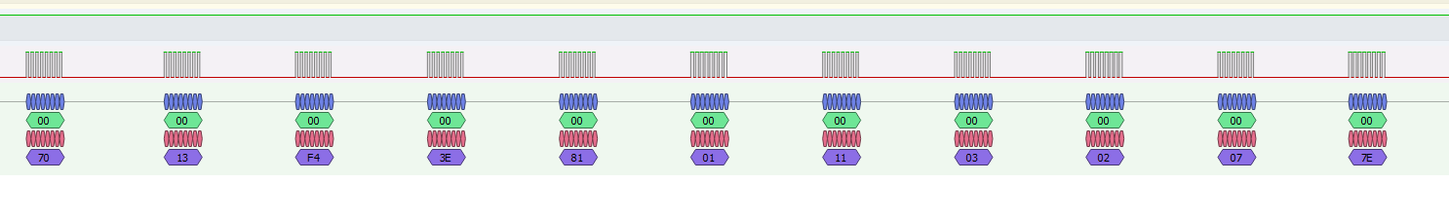
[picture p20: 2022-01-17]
WiSafeCommunicationAnalysis/PulseViewCaptures/remote test (wst) TEST1.png

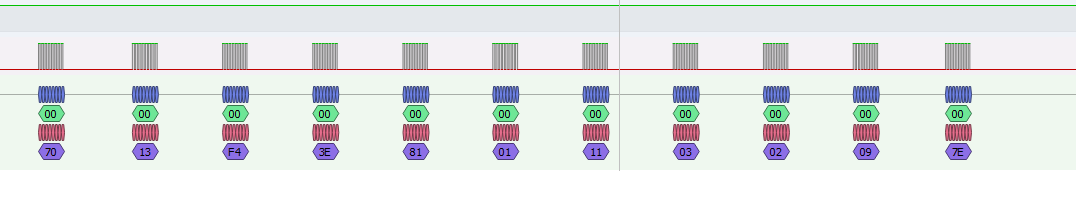
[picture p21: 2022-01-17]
WiSafeCommunicationAnalysis/PulseViewCaptures/remote test (wst) TEST3.png

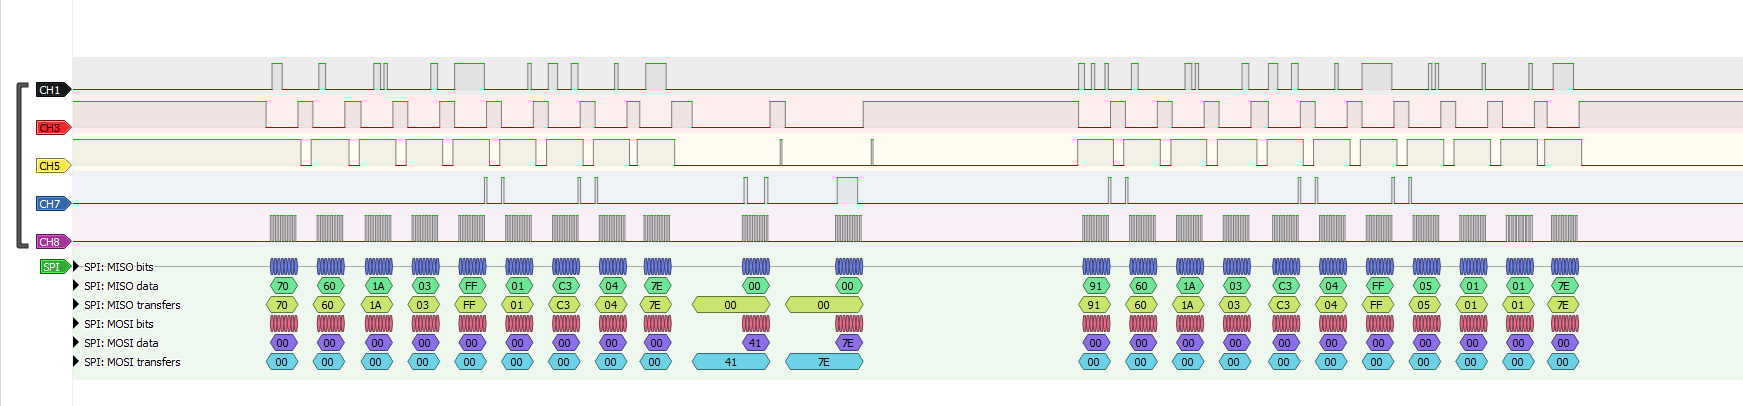
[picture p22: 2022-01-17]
WiSafeCommunicationAnalysis/PulseViewCaptures/strobe/self-test0.png

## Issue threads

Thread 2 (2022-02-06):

Command to query info about individual SID position?

Tho85, 2022-02-06:
Hi,

I also did some research into my network of ST-630-DET devices. I created a small breakout PCB where you can easily connect a logic analyzer to the SPI bus. I was able to attach a Arduino Pro Mini 3.3V to it, so I didn't need any logic level converters. My firmware for the Arduino is a more or less generic SPI slave to UART converter, and I was able to connect it to an ESP8266 programmed with ESPHome and integrate the alarms into Home Assistant. At this point I found your repo, which would have saved me quite some time in the past months... :sweat_smile:

As a next step I would like to create a generic WiSafe2-to-MQTT gateway. For this I would like to be able to query the radio module for all known devices. For all that I know, the command `D3 03 7E` queries the radio module for its SID map (map of devices), and a response of `D4 03 81 00 00 00 00 00 00 00 7E` indicates that the module knows of devices at SID 0 and 7 (`0x81 = 1000001b`). However, I can't find any information on how to query more data for the individual SID positions.

Do you know a command that I can send to the radio to query more details for a specific SID position? Could you maybe try to extract it from your FireAngel gateway's serial console? It looks like at [this point](https://github.com/C19HOP/WiSafe2-to-HomeAssistant-Bridge/blob/master/FireAngelProConnectedGateway/debug-capture.log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) the gateway would have sent such a command to the module, if it hadn't seen all devices before.

Thanks in advance!

PS: Interestingly, some of my ST-630-DET devices present themselves with 4-byte serial numbers, making all packets a byte longer. This may be a small challenge...

Tho85, 2022-02-06:
OK, I think I _may_ have found it by trial and error. The command `D3 06 07 7E` returns a positive reply (`46 7E`), and after some time I get this message: `D4 06 07 63 8E 00 AA F3 D8 6C 0C 00 02 7E`. It looks like this is diagnostic information from the device at SID position 7, since the device's serial number (`D8 6C 0C`) shows up in the response. So I understand the command as follows:

* `D3`: Send command
* `06`: Show details for SID position
* `07`: SID position 7 (as in `1<<7`, aka `0x80`)
* `7E`: End of packet

Closing this issue for now.

C19HOP, 2022-02-08:
Hi Tho85,

If I were going the wireless route, I'd have arrived at the same place.
i.e.
3.3v Pro Mini >> ESP8266

I wasn't sold on the idea only because:
- I wanted to reduce the failure points (additional MCU and WiFi)
- I was new to HA and still learning how to create integrations.

However, retrospectively, yes, I can see that MQTT is likely to be preferred by many.
If I were starting over, I noted that there are some SPI slave examples for the ESP32. So even better, we could probably do it all in one chip :)

The only D3 commands I had observed myself were used for radio get-pairing-status, enter-pairing-mode, erase-pairing.
I did not observe any 'query for known devices' messages.
Seems like great potential for a simpler automation.

Cheers.

Tho85, 2022-02-08:
> If I were starting over, I noted that there are some SPI slave examples for the ESP32. So even better, we could probably do it all in one chip :)

Been there, done that. I tried an ESP32 with the SPI slave driver, however it was very unstable. I observed hiccups on the SPI clock line, as well as many dropped transactions, and that was where I cancelled the experiment. Most of the SPI slave logic is [implemented in software](https://github.com/espressif/esp-idf/blob/master/components/driver/spi_slave.c), and that seems to be unstable.

The ATmega328p / Arduino Pro Mini on the other hand does all of the SPI slave handling in hardware, throws an interrupt as soon as it receives data, and allows for a much more stable solution IMO. I've been using that in the last days and it looks rock solid to me.

Tho85, 2022-02-15:
> PS: Interestingly, some of my ST-630-DET devices present themselves with 4-byte serial numbers, making all packets a byte longer. This may be a small challenge...

Posting this here, in case anyone stumbles across this in the far future. My assumption was wrong, the devices all only have 3-byte addresses. However, my device presented itself with a serial number of `7D 01 6C 0C`. The real serial number seems to be `7E 6C 0C`, but since `7E` is the stop word used for communication (always the last byte of a transaction), it is converted to `7D 01 6C 0C`.

--> `7E` is replaced by `7D 01`, and `7D` is replaced by `7D 02`. Not only for serial numbers, but for all fields. So if you ever come across a transaction that is a byte longer than expected, this may be the explanation.

Tho85, 2022-03-12:
FYI, I've got the first prototype of my gateway up and running: https://github.com/Tho85/ws2mqtt

Closed 2022-02-06.

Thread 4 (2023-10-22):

Can you help with a hardware build

UK-JustinSmall, 2023-10-22:
Prepared to pay for the parts but need someone to put this together as don't feel confident enough to make this myself. Can you help me?

ian-morgan99, 2024-07-23:
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

If I get this sucker working , maybe 😀

tschubb, 2025-07-04:
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

Hi,

I have some spare, happy send you one.

Cheers,
Tom

Michael-1357, 2025-07-04:
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

Hi Tom,

That's great.  If github has a private message system sadly I am missing it.   So, could kindly email me at heave-undead-crank@duck.com

Kind regards,

Michael

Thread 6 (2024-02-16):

Update Home Assistant configuration

ssillen, 2024-02-16:
I happily used your project, thank you for the hard work.
However, I upgraded the sensors config according to the latest Home Assistant principles (2024.1).
The availability of the sensors is also automatically updated, based on heartbeat & "missing" events.
I'm using the /dev/serial/by-id/ as serial_port, because the /dev/ttyUSB can sometimes change when (un)plugging new devices or doing a restart.
Hopefully this might be of use.

config.yaml:
```yaml
tts:
  - platform: google_cloud
    base_url: http://192.168.0.200:8123
    key_file: googlecloud.json
    voice: en-GB-Wavenet-B
    encoding: linear16
    speed: 0.9
    pitch: -1.0

notify:
  - platform: group
    name: all_mobile_app_devices
    services:
      - service: mobile_app_iphone_1
      - service: mobile_app_iphone_2

recorder:
  exclude:
    entity_globs:
      - sensor.fireangel_data
      #Excludes the heartbeat updates from the radio (changes every few seconds)

#-----------------
#FireAngel Sensors
#-----------------
sensor:
  # FireAngel Gateway
  - platform: serial
    name: "FireAngel Data"
    serial_port: /dev/serial/by-id/usb-1a86_USB2.0-Ser_-if00-port0
    baudrate: 115200

template:
  #-----------------
  #FireAngel Sensors
  #-----------------
  - binary_sensor:
      - name: "FireAngel Gateway Connectivity"
        unique_id: fireangel_heartbeat
        device_class: connectivity
        state: >
          {% if states('sensor.fireangel_data') !='unknown' and (now() - states.sensor.fireangel_data.last_changed).total_seconds() < 125 %}
            on
          {% else %}
            off
          {% endif %}

  - trigger:
      - platform: state
        entity_id: sensor.fireangel_data
      - platform: state
        entity_id: binary_sensor.fireangel_gateway_connectivity
    sensor:
      - name: "FireAngel Messages"
        unique_id: fireangel_messages
        icon: mdi:message-processing
        state: >
          {% if not '{' in states('sensor.fireangel_data') %}
            {{states('sensor.fireangel_data')}}
          {% endif %}
      - name: "FireAngel Built in Test Function"
        unique_id: fireangel_pseudo_firmware_alarm
        state: >
          {% if state_attr('sensor.fireangel_data', 'device')=='a5b813'.upper() %}
            {{ state_attr('sensor.fireangel_data', 'event') }}
          {% endif %}
    binary_sensor:
      - name: "FireAngel Radio"
        unique_id: fireangel_radio
        device_class: connectivity
        availability: "{{ states('binary_sensor.fireangel_gateway_connectivity') == 'on' }}"
        state: >
          {% if 'INIT OK' in states('sensor.fireangel_data') %}
            on
          {% elif 'Radio not ready - Trying to reset' in states('sensor.fireangel_data') or states('sensor.fireangel_data') == 'Initializing radio' %}
            off
          {% else %}
            {{this.state}}
          {% endif %}
      #------------------------------------
      #A76F18 | FP1720W2-R | Heat | Kitchen
      #------------------------------------
      - name: "FireAngel Heat Alarm Kitchen Connectivity"
        unique_id: fireangel_kitchen_connectivity
        device_class: connectivity
        availability: "{{ states('binary_sensor.fireangel_gateway_connectivity') == 'on' and states('binary_sensor.fireangel_radio') != 'off' }}"
        state: >
          {% if state_attr('sensor.fireangel_data', 'device')=='a76f18'.upper() %}
            {% if state_attr('sensor.fireangel_data', 'event')=='MISSING' %}
              off
            {% else %}
              on
            {% endif %}
          {% else %}
            {{this.state}}
          {% endif %}
      - name: "FireAngel Heat Alarm Kitchen Heat Status"
        unique_id: fireangel_kitchen_heat_status
        device_class: heat
        availability: "{{ states('binary_sensor.fireangel_heat_alarm_kitchen_connectivity') == 'on' }}"
        state: >
          {% if state_attr('sensor.fireangel_data', 'event')=='SILENCE' %}
            off
          {% elif state_attr('sensor.fireangel_data', 'device')=='a76f18'.upper() %}
            {% if state_attr('sensor.fireangel_data', 'event')=='FIRE EMERGENCY' %}
              on
            {% else %}
              {{this.state}}
            {% endif %}
          {% else %}
            {{this.state}}
          {% endif %}
      - name: "FireAngel Heat Alarm Kitchen CO Status"
        unique_id: fireangel_kitchen_co_status
        device_class: carbon_monoxide
        availability: "{{ states('binary_sensor.fireangel_heat_alarm_kitchen_connectivity') == 'on' }}"
        state: >
          {% if state_attr('sensor.fireangel_data', 'event')=='SILENCE' %}
            off
          {% elif state_attr('sensor.fireangel_data', 'device')=='a76f18'.upper() %}
            {% if state_attr('sensor.fireangel_data', 'event')=='CARBON MONOXIDE EMERGENCY' %}
              on
            {% else %}
              {{this.state}}
            {% endif %}
          {% else %}
            {{this.state}}
          {% endif %}
      - name: "FireAngel Heat Alarm Kitchen Heat Test"
        unique_id: fireangel_kitchen_heat_test
        device_class: problem
        icon: mdi:thermometer
        availability: "{{ states('binary_sensor.fireangel_heat_alarm_kitchen_connectivity') == 'on' }}"
        state: >
          {% if state_attr('sensor.fireangel_data', 'device')=='a76f18'.upper() %}
            {% if state_attr('sensor.fireangel_data', 'event')=='FIRE TEST' %}
              {% if state_attr('sensor.fireangel_data', 'result')=='PASS' %}
                off
              {% else %}
                on
              {% endif %}
            {% else %}
              {{this.state}}
            {% endif %}
          {% else %}
            {{this.state}}
          {% endif %}
      - name: "FireAngel Heat Alarm Kitchen CO Test"
        unique_id: fireangel_kitchen_co_test
        device_class: problem
        icon: mdi:molecule-co
        availability: "{{ states('binary_sensor.fireangel_heat_alarm_kitchen_connectivity') == 'on' }}"
        state: >
          {% if state_attr('sensor.fireangel_data', 'device')=='a76f18'.upper() %}
            {% if state_attr('sensor.fireangel_data', 'event')=='CARBON MONOXIDE TEST' %}
              {% if state_attr('sensor.fireangel_data', 'result')=='PASS' %}
                off
              {% else %}
                on
              {% endif %}
            {% else %}
              {{this.state}}
            {% endif %}
          {% else %}
            {{this.state}}
          {% endif %}
      - name: "FireAngel Heat Alarm Kitchen Battery"
        unique_id: fireangel_kitchen_battery
        device_class: battery
        availability: "{{ states('binary_sensor.fireangel_heat_alarm_kitchen_connectivity') == 'on' }}"
        state: >
          {% if state_attr('sensor.fireangel_data', 'device')=='a76f18'.upper() and states.sensor.fireangel_data.attributes.battery is defined %}
            {% if state_attr('sensor.fireangel_data', 'battery')=='LOW' %}
              on
            {% else %}
              off
            {% endif %}
          {% else %}
            {{this.state}}
          {% endif %}
      - name: "FireAngel Heat Alarm Kitchen On Base"
        unique_id: fireangel_kitchen_onbase
        device_class: presence
        availability: "{{ states('binary_sensor.fireangel_heat_alarm_kitchen_connectivity') == 'on' }}"
        state: >
          {% if state_attr('sensor.fireangel_data', 'device')=='a76f18'.upper() and states.sensor.fireangel_data.attributes.base is defined %}
            {% if state_attr('sensor.fireangel_data', 'base')=='OFF' %}
              off
            {% else %}
              on
            {% endif %}
          {% else %}
            {{this.state}}
          {% endif %}
    #------------------------------------
    #2D8D01 | FP2620W2 | Smoke | Bedroom
    #------------------------------------
    - name: "FireAngel Smoke Alarm Bedroom Connectivity"
      unique_id: fireangel_bedroom_connectivity
      device_class: connectivity
      availability: "{{ states('binary_sensor.fireangel_gateway_connectivity') == 'on' and states('binary_sensor.fireangel_radio') != 'off' }}"
      state: >
        {% if state_attr('sensor.fireangel_data', 'device')=='2d8d01'.upper() %}
          {% if state_attr('sensor.fireangel_data', 'event')=='MISSING' %}
            off
          {% else %}
            on
          {% endif %}
        {% else %}
          {{this.state}}
        {% endif %}
    - name: "FireAngel Smoke Alarm Bedroom Smoke Status"
      unique_id: fireangel_bedroom_smoke_status
      device_class: smoke
      availability: "{{ states('binary_sensor.fireangel_smoke_alarm_bedroom_connectivity') == 'on' }}"
      state: >
        {% if state_attr('sensor.fireangel_data', 'event')=='SILENCE' %}
          off
        {% elif state_attr('sensor.fireangel_data', 'device')=='2d8d01'.upper() %}
          {% if state_attr('sensor.fireangel_data', 'event')=='FIRE EMERGENCY' %}
            on
          {% else %}
            {{this.state}}
          {% endif %}
        {% else %}
          {{this.state}}
        {% endif %}
    - name: "FireAngel Smoke Alarm Bedroom CO Status"
      unique_id: fireangel_bedroom_co_status
      device_class: carbon_monoxide
      availability: "{{ states('binary_sensor.fireangel_smoke_alarm_bedroom_connectivity') == 'on' }}"
      state: >
        {% if state_attr('sensor.fireangel_data', 'event')=='SILENCE' %}
          off
        {% elif state_attr('sensor.fireangel_data', 'device')=='2d8d01'.upper() %}
          {% if state_attr('sensor.fireangel_data', 'event')=='CARBON MONOXIDE EMERGENCY' %}
            on
          {% else %}
            {{this.state}}
          {% endif %}
        {% else %}
          {{this.state}}
        {% endif %}
    - name: "FireAngel Smoke Alarm Bedroom Smoke Test"
      unique_id: fireangel_bedroom_smoke_test
      device_class: problem
      icon: mdi:thermometer
      availability: "{{ states('binary_sensor.fireangel_smoke_alarm_bedroom_connectivity') == 'on' }}"
      state: >
        {% if state_attr('sensor.fireangel_data', 'device')=='2d8d01'.upper() %}
          {% if state_attr('sensor.fireangel_data', 'event')=='FIRE TEST' %}
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
NeoDuder, 2024-06-22:
Hey,

Thanks for this, I've just updated my config and it looks a lot cleaner.
I am, however having an issue with connectivity. Any ideas...

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

ssillen, 2024-06-22:
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

You have to initialize the connectivity of all the smoke sensors to "on". The bridge needs a message from each smoke sensor to confirm it's connected, because it doesn't know the initial state. So you can trigger an event on zacht smoke sensor by triggering an alarm or removing the smoke sensor from the base. Or you can set the connectivity via the Developer Tools.

NeoDuder, 2024-06-22:
Thanks for the reply. I have initiated a test, all alarms sound. I've removed all of the alarms from their base and refitted. No change in any of the statuses.

ssillen, 2024-06-22:
Gateway connectivity and radio are ok, the connectivity sensor of each smoke sensor is available, so it would have to be in the configuration of the smoke sensor connectivity sensor.
Please check the device id's in your configuration. Compare with the input you get from sensor.fireangel_data when triggering an event on your smoke sensor.

NeoDuder, 2024-06-23:
Ok, so done some experimentation.

If I initiate a test from each alarm, the section for that alarm on my dashboard gets updated. I've now done that on all alarms, and all statuses are showing. However, if I initiate an alarm situation on any alarm, the statuses do not update. I held a lighter under my Kitchen Heat Sensor until it went off. All alarms sounded, "FireAngel Messages" on my dashboard showed the emergency message, but the status pages remain unchanged, with the kitchen still showing "Heat Status: Normal"

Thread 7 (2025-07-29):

W2-Module seems not to respond

nbrgmn, 2025-07-29:
I found this project already 2 years ago, but didn't find a time slot to try it out. But today I assembled and soldered the module (see attached photos), flashed the software and started the integration into Home Assistant.

First it looked quite good and after a few resets I got the incrementing heartbeat message. But after a restart of Home Assistant, due to the shell commands, I'm stucking with 'Radio not ready - Trying to reset' in the initRadio-method. The spi communication seems not to work as only 0 comes as response.

Does anyone have an advice? I hope this project is still alive, as I haven't found many alternatives yet.

Thank you in advance.

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

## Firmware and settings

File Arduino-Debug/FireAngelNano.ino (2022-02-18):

#include<SPI.h>

#define IRQline 9
#define directModePin 2

volatile boolean SPIreceived;
volatile byte Slavereceived, Slavesend;
int ByteFromSerial = 0;
int IRQState = 1;
int IRQLastState = 1;
int sendWait = 0;
const int BUFFER_SIZE = 25;                       // Buffer for SPI and Serial. All commands must be less than the size this buffer
byte serialBuffer[BUFFER_SIZE];
byte spiBuffer[BUFFER_SIZE];
int spiBufferIndex = 0;
int spiBufferDumpCounter = 0;
boolean radioReceiveBufferReady = false;
boolean directMode = false;
int maxInitAttempts = 50;                        //MAX number of attempts to Init Radio
unsigned int heartBeatInterval = 25000;           // Heartbeat interval (in milliseconds)
unsigned long lastHeartBeat = 0;
int heartBeatValue = 0;


//------------------------EMBEDDED DEVICE INFO GOES HERE-------------------------------
// When sending data to other alarms, this is the DeviceID and ModelID which other 
// devices on the network will receive data from 

// Device ID
// Just needs to be unique
byte DevId0 = 0xA5;
byte DevId1 = 0xB8;
byte DevId2 = 0x13;

// Device Model 
// Known devices are (ED:08==FP2620W2,  11:03==WST-630,  78:03==W2-CO-10X,  C3:04==W2-SVP-630)
byte DevModel0 = 0x11;
byte DevModel1 = 0x03;
//--------------------------------------------------------------------------------------



void(* resetFunc) (void) = 0;                                 //Reset Arduino if radio init failed



void setup()
{
  pinMode(IRQline, OUTPUT);
  pinMode(directModePin, INPUT_PULLUP);
  pinMode(MISO, OUTPUT);                                       //Sets MISO as OUTPUT
  SPCR |= _BV(SPE);                                            //SPI = Slave Mode
  SPIreceived = false;
  SPI.attachInterrupt();                                       //Interrupt ON
  Serial.begin(115200);
  directMode = digitalRead(directModePin);
  delay(5000);                                                 //Allow radio stabilise first
  sendCMDToRadio(NULL, 0, true);
  for (int i = 0; i <= maxInitAttempts; i++)
  {
    if (initRadio() == true) {
      flushSPIbuffer();
      break;
    }
    if (i == (maxInitAttempts)) {
      if (directMode == true) {
        Serial.write(0x15);
        Serial.write(0x7E);
      } else {
        Serial.println("Radio not ready - Trying to reset");
        delay(500);  
      }
        resetFunc();
    }
  }
}



ISR (SPI_STC_vect)
{
  Slavereceived = SPDR;
  SPIreceived = true;
}



boolean initRadio()
{
  byte cmdTemplate[] = {0xD3, 0x19, 0x50, 0x00, 0x7E}; // default init sequence
  //byte cmdTemplate[] = {0xD3, 0x14, 0x8E, 0x7E}; // alternative  init sequence
  
  sendCMDToRadio(cmdTemplate, sizeof(cmdTemplate), true);
  if (radioReceiveBufferReady == false)  {
    Serial.print("No reply from radio. SPI Buffer= "); for(int i = 0; i < sizeof(spiBuffer); i++){Serial.print(spiBuffer[i],HEX);}Serial.println();    //  [debug] print raw response from radio
  //Serial.print(".");
    return (false);
    }
  else
  {    
    
   // if (true == true) {   // [debug] bypass init-ok check
  if (spiBuffer[0] == (0x46)) {
    
     if (directMode == true) {
        Serial.write(0x06);Serial.write(0x7E);
  } else {
      Serial.print("INIT OK. SPI Buffer= "); for(int i = 0; i < sizeof(spiBuffer); i++){Serial.print(spiBuffer[i],HEX);}Serial.println();    //  [debug] print raw response from radio
    //Serial.println("INIT OK");
  }
  return (true);
    }
    else
    {
    Serial.print("Expected 467E, but got something else. SPI Buffer= "); for(int i = 0; i < sizeof(spiBuffer); i++){Serial.print(spiBuffer[i],HEX);}Serial.println();    //  [debug] print raw response from radio
  //Serial.print("-");
  return (false);
    }
  }
}



void checkIfSPIbufferIsStagnant()
{
  if (spiBufferIndex > 0)
  { // check the SPI incoming buffer isn't stagnant
    spiBufferDumpCounter++;
    if (spiBufferDumpCounter > 1000)
    {
      flushSPIbuffer();
    }
  }
}



void flushSPIbuffer()
{
  spiBufferIndex = 0;
  memset(spiBuffer, 0, sizeof(spiBuffer));
  spiBufferDumpCounter = 0;
  radioReceiveBufferReady = false;
}



void SendTemplateToRadio(byte CMD)
{
int retries = 0;
retry:
lastHeartBeat = millis();                                                                                          //Delay the next heartbeat to ensure it doesnt come instantly after a message

  if (CMD == (0x31))                                                                                               //TEST - CO
  {
    retries++;
    byte cmdTemplate[] = {0x70, DevId0, DevId1, DevId2, 0x41, 0x01, DevModel0, DevModel1, 0x7E};
    byte cmdTemplate2[] = {0x91, DevId0, DevId1, DevId2, DevModel0, DevModel1, 0x41, 0x05, 0x00, 0x02, 0x7E};
    sendCMDToRadio(cmdTemplate, sizeof(cmdTemplate), true);
    if ((spiBuffer[0] != (0x41)) || (spiBuffer[1] != (0x7E))){ 
      if (retries > 3) {Serial.println("CMD FAIL");return;} else {delay (500); goto retry; }
    }
    sendCMDToRadio(cmdTemplate2, sizeof(cmdTemplate2), true);
    Serial.println("CMD OK");
    delay (1000);
    Serial.print("{\"device\":\"");
    if (DevId0 <= 0x0F) {Serial.print("0");} Serial.print((DevId0), HEX);
    if (DevId1 <= 0x0F) {Serial.print("0");} Serial.print((DevId1), HEX);
    if (DevId2 <= 0x0F) {Serial.print("0");} Serial.print((DevId2), HEX);
    Serial.println("\", \"event\":\"CARBON MONOXIDE TEST\", \"result\":\"PASS\"}"); 
  }
  
  if (CMD == (0x32))                                                                                               //TEST - SMOKE
  {
    retries++;
    byte cmdTemplate[] = {0x70, DevId0, DevId1, DevId2, 0x81, 0x01, DevModel0, DevModel1, 0x7E};
    byte cmdTemplate2[] = {0x91, DevId0, DevId1, DevId2, DevModel0, DevModel1, 0x81, 0x05, 0x00, 0x02, 0x7E};
    sendCMDToRadio(cmdTemplate, sizeof(cmdTemplate), true);
    if ((spiBuffer[0] != (0x41)) || (spiBuffer[1] != (0x7E))) {
      if (retries > 3) {Serial.println("CMD FAIL");return;} else {delay (500); goto retry; }
    }
    sendCMDToRadio(cmdTemplate2, sizeof(cmdTemplate2), true);
    Serial.println("CMD OK");
    delay (1000);
    Serial.print("{\"device\":\"");
    if (DevId0 <= 0x0F) {Serial.print("0");} Serial.print((DevId0), HEX);
    if (DevId1 <= 0x0F) {Serial.print("0");} Serial.print((DevId1), HEX);
    if (DevId2 <= 0x0F) {Serial.print("0");} Serial.print((DevId2), HEX);
    Serial.println("\", \"event\":\"FIRE TEST\", \"result\":\"PASS\"}"); 
  }
  
  if (CMD == (0x33))                                                                                              //TEST - SMOKE+CO
  {
    retries++;
    byte cmdTemplate[] = {0x70, DevId0, DevId1, DevId2, 0xFF, 0x01, DevModel0, DevModel1, 0x7E};
    byte cmdTemplate2[] = {0x91, DevId0, DevId1, DevId2, DevModel0, DevModel1, 0xFF, 0x05, 0x00, 0x02, 0x7E};
    sendCMDToRadio(cmdTemplate, sizeof(cmdTemplate), true);
    if ((spiBuffer[0] != (0x41)) || (spiBuffer[1] != (0x7E))) {
     if (retries > 3) {Serial.println("CMD FAIL");return;} else {delay (500); goto retry; }
    }
    sendCMDToRadio(cmdTemplate2, sizeof(cmdTemplate2), true);
    Serial.println("CMD OK");
    delay (1000);
    Serial.print("{\"device\":\"");
    if (DevId0 <= 0x0F) {Serial.print("0");} Serial.print((DevId0), HEX);
    if (DevId1 <= 0x0F) {Serial.print("0");} Serial.print((DevId1), HEX);
    if (DevId2 <= 0x0F) {Serial.print("0");} Serial.print((DevId2), HEX);
    Serial.println("\", \"event\":\"TEST\", \"result\":\"PASS\"}"); 
  }
  
  if (CMD == (0x34))                                                                                              //EMERGENCY - CO
  {
    retries++;
    byte cmdTemplate[] = {0x50, DevId0, DevId1, DevId2, 0x41, 0x00, 0x7E};
    sendCMDToRadio(cmdTemplate, sizeof(cmdTemplate), true);
    if ((spiBuffer[0] != (0x46)) || (spiBuffer[1] != (0x7E))) {
      if (retries > 5) {Serial.println("CMD FAIL");return;} else {delay (500); goto retry; }
    }
    Serial.println("CMD OK");
    delay (1000);
    Serial.print("{\"device\":\"");
    if (DevId0 <= 0x0F) {Serial.print("0");} Serial.print((DevId0), HEX);
    if (DevId1 <= 0x0F) {Serial.print("0");} Serial.print((DevId1), HEX);
    if (DevId2 <= 0x0F) {Serial.print("0");} Serial.print((DevId2), HEX);
    Serial.println("\", \"event\":\"CARBON MONOXIDE EMERGENCY\"}"); 
  }
  
  if (CMD == (0x35))                                                                                            //EMERGENCY - SMOKE
  {
    retries++;
    byte cmdTemplate[] = {0x50, DevId0, DevId1, DevId2, 0x81, 0x00, 0x7E};
    sendCMDToRadio(cmdTemplate, sizeof(cmdTemplate), true);
    if ((spiBuffer[0] != (0x46)) || (spiBuffer[1] != (0x7E))) {
       if (retries > 5) {Serial.println("CMD FAIL");return;} else {delay (500); goto retry; }
    }
    Serial.println("CMD OK");
    delay (1000);
    Serial.print("{\"device\":\"");
    if (DevId0 <= 0x0F) {Serial.print("0");} Serial.print((DevId0), HEX);
    if (DevId1 <= 0x0F) {Serial.print("0");} Serial.print((DevId1), HEX);
    if (DevId2 <= 0x0F) {Serial.print("0");} Serial.print((DevId2), HEX);
    Serial.println("\", \"event\":\"FIRE EMERGENCY\"}"); 
  }
  
  if (CMD == (0x36))                                                                                            //SILENCE - (As CO device)
  {
    retries++;
    byte cmdTemplate[] = {0x61, DevId0, DevId1, DevId2, 0x40, 0x01, 0x7E};
    sendCMDToRadio(cmdTemplate, sizeof(cmdTemplate), true);
    if ((spiBuffer[0] != (0x46)) || (spiBuffer[1] != (0x7E))) {
      if (retries > 5) {Serial.println("CMD FAIL");return;} else {delay (500); goto retry; }
    }
    Serial.println("CMD OK");
    delay (1000);
    Serial.print("{\"device\":\"");
    if (DevId0 <= 0x0F) {Serial.print("0");} Serial.print((DevId0), HEX);
    if (DevId1 <= 0x0F) {Serial.print("0");} Serial.print((DevId1), HEX);
    if (DevId2 <= 0x0F) {Serial.print("0");} Serial.print((DevId2), HEX);
    Serial.println("\", \"event\":\"SILENCE\"}"); 
  }
  
  if (CMD == (0x37))                                                                                          //SILENCE - (As SMOKE device)
  {
    retries++;
    byte cmdTemplate[] = {0x61, DevId0, DevId1, DevId2, 0x80, 0x01, 0x7E};
    sendCMDToRadio(cmdTemplate, sizeof(cmdTemplate), true);
    if ((spiBuffer[0] != (0x46)) || (spiBuffer[1] != (0x7E))) {
    if (retries > 5) {Serial.println("CMD FAIL");return;} else {delay (500); goto retry; }
    }
    Serial.println("CMD OK");
    delay (1000);
    Serial.print("{\"device\":\"");
    if (DevId0 <= 0x0F) {Serial.print("0");} Serial.print((DevId0), HEX);
    if (DevId1 <= 0x0F) {Serial.print("0");} Serial.print((DevId1), HEX);
    if (DevId2 <= 0x0F) {Serial.print("0");} Serial.print((DevId2), HEX);
    Serial.println("\", \"event\":\"SILENCE\"}"); 
  }
  
  if (CMD == (0x38))                                                                                          //GET PAIRING STATE
  {
    retries++;
    byte cmdTemplate[] = {0xD3, 0x03, 0x7E};
    sendCMDToRadio(cmdTemplate, sizeof(cmdTemplate), true);
    if ((spiBuffer[0] != (0xD4)) || (spiBuffer[10] != (0x7E))) {
      if (retries > 5) {Serial.println("CMD FAIL");return;} else {delay (500); goto retry; }
    }
    if (spiBuffer[2] != (0x00)) {
      Serial.println("NETWORK PAIRED");
      return;
    }
    Serial.println("NETWORK UNPAIRED");
  }
  
  if (CMD == (0x39))                                                                                            //START PAIRING MODE
  {
    retries++;
    byte cmdTemplate[] = {0xD3, 0x03, 0x7E};
    sendCMDToRadio(cmdTemplate, sizeof(cmdTemplate), true);
    if ((spiBuffer[0] != (0xD4)) || (spiBuffer[10] != (0x7E))) {
      if (retries > 3) {Serial.println("CMD FAIL");return;} else {delay (500); goto retry; }
    }
    if (spiBuffer[2] != (0x00)) {
      Serial.println("ERROR NETWORK IS ALREADY PAIRED");
      return;
    }
    flushSPIbuffer();
    retries++;
    byte cmdTemplate2[] = {0xD3, 0x12, 0x01, 0x7E};
    byte cmdTemplate3[] = {0x91, DevId0, DevId1, DevId2, DevModel0, DevModel1, 0xFF, 0x05, 0x01, 0x01, 0x7E};
    sendCMDToRadio(cmdTemplate2, sizeof(cmdTemplate2), true);
    if ((spiBuffer[0] != (0x46)) || (spiBuffer[1] != (0x7E))) {
       if (retries > 4) {Serial.println("CMD FAIL");return;} else {delay (500); goto retry; }
    }
    flushSPIbuffer();
    retries++;
    sendCMDToRadio(NULL, 0, true);
    if ((spiBuffer[0] != (0x41)) || (spiBuffer[1] != (0x7E))) {
       if (retries > 5) {Serial.println("CMD FAIL");return;} else {delay (500); goto retry; }
    }
    sendCMDToRadio(cmdTemplate3, sizeof(cmdTemplate3), true);
    Serial.println("NETWORK PAIRING MODE ACTIVATED");
    for (int i = 0; i <= 20; i++) {
      delay(1000);
      Serial.print("=");
    }
    flushSPIbuffer();
    Serial.println("");
    sendCMDToRadio(cmdTemplate, sizeof(cmdTemplate), true);
    if ((spiBuffer[0] != (0xD4)) || (spiBuffer[10] != (0x7E))) {
      Serial.println("CMD FAIL(4)");
      return;
    }
    if (spiBuffer[2] != (0x00)) {
      Serial.println("NETWORK IS NOW PAIRED");
      return;
    }
    Serial.println("NETWORK IS STILL UNPAIRED");
  }
}



void sendCMDToRadio(byte cmd[], int cmdSize, boolean waitForReply)
{
  int cmdTTL = 0;
  for (byte i = 0; i < cmdSize; i++) {
    WriteByteToRadio(cmd[i]);
  }
  if (waitForReply == true)
  {
    while ((radioReceiveBufferReady == false) && (cmdTTL < 2500))
    {
      ReadByteFromRadio();
      cmdTTL++;
      delayMicroseconds(50);
    }
  }
}



void ReadByteFromSerial()
{ // check for incoming byte from Serial
  if (Serial.available() > 0) {
    delay(4);                                                                   // wait for transmission (Buffer = 25 | 9600bps = 1.04ms/char =30ms | 115200bps = 0.097ms/char =3ms)
    int rlen = Serial.readBytesUntil(0x7E, serialBuffer, BUFFER_SIZE);          // read 25 bytes, until timeout, or 7E char
    //   if ((serialBuffer[0] == (0x3E)) && (serialBuffer[1] == (0x3E)))
    if (directMode == false)
    {
      SendTemplateToRadio(serialBuffer[0]);
      delay(500);                                                               // avoid returning to the main loop too soon (which will flush SPI buffer)
    }
    else
    {
      for (int i = 0; i < rlen; i++)                                            // send raw hex to radio
      {
        WriteByteToRadio(serialBuffer[i]);                                      // send data to the radio... could check it for special commands first
      }
      WriteByteToRadio(0x7E);                                                   // replace the 7E char (removed by serial.readBytesUntil)
    }
  }                                         
  if (Serial.available()) {                                                     //Send carriage return characters to a black hole if they've followed the 0x7E terminator
    if ((Serial.peek() == (0x0A)) || (Serial.peek() == (0x0D))) {
      byte blackhole  = Serial.read();
    }
  }
  if (Serial.available()) {
    if ((Serial.peek() == (0x0A)) || (Serial.peek() == (0x0D))) {
      byte blackhole  = Serial.read();
    }
  }
}



void ReadByteFromRadio()
{
  IRQState = digitalRead(SS);
  if (IRQState != IRQLastState)
  {
    if (IRQState == HIGH)
    {
      digitalWrite(IRQline, HIGH);
      delayMicroseconds(8);
      digitalWrite(IRQline, LOW);
    }
    IRQLastState = IRQState;
    if (SPIreceived == true)
    {
      spiBuffer[spiBufferIndex++] = Slavereceived;
      spiBufferDumpCounter = 0;
      if (Slavereceived == 0x7E) {
        radioReceiveBufferReady = true;
      }
    }
    (SPDR = 0);
    (SPIreceived = false);
  }
}



void WriteByteToRadio(byte byteToSend)
{
  digitalWrite(IRQline, HIGH);                    //set IRQ high
  sendWait = 0;
  while (digitalRead(SS) == HIGH)
  {
    delayMicroseconds(5);                         //wait for CS to go low
    sendWait++;
    if (sendWait >= 1000)
    { //timeout waiting for CS
      break;
    }
  }
  sendWait = 0;
  SPDR = byteToSend;                              //put data from Slave to Master on to SPI
  sendWait = 0;
  while (digitalRead(SS) == LOW)
  {
    delayMicroseconds(5);                         //wait for CS to return high
    sendWait++;
    if (sendWait >= 1000)
    { //timeout waiting for CS
      break;
    }
  }
  digitalWrite(IRQline, LOW);                     //set IRQ low
  (SPDR = 0);
  (SPIreceived = false);
}



void processRadioResponse()
{
lastHeartBeat = millis();                                                                       //Delay the next heartbeat to ensure it doesnt come instantly after a message
  
  if (spiBuffer[0] == 0x70)                                                                     // Test Event
  {
    Serial.print("{\"device\":\"");
    if (spiBuffer[1] <= 0x0F) {Serial.print("0");} Serial.print((spiBuffer[1]), HEX);
    if (spiBuffer[2] <= 0x0F) {Serial.print("0");} Serial.print((spiBuffer[2]), HEX);
    if (spiBuffer[3] <= 0x0F) {Serial.print("0");} Serial.print((spiBuffer[3]), HEX);
    Serial.print("\", \"model\":\"");
    if (spiBuffer[6] <= 0x0F) {Serial.print("0");} Serial.print((spiBuffer[6]), HEX);
    if (spiBuffer[7] <= 0x0F) {Serial.print("0");} Serial.print((spiBuffer[7]), HEX);
    Serial.print("\", \"event\":\"");
    if (spiBuffer[4] == 0x81) {Serial.print("FIRE ");}
    if (spiBuffer[4] == 0x82) {Serial.print("FIRE ");}
    if (spiBuffer[4] == 0x41) {Serial.print("CARBON MONOXIDE ");}
    //if (spiBuffer[4] == 0xFF) {Serial.print("ALL");}
    Serial.print("TEST\", \"result\":\"");
    if (spiBuffer[5] == 0x01) {Serial.print("PASS\", \"base\":\"ON\", \"battery\":\"OK\"");} 
    else {Serial.print("FAIL\", \"base\":\"ON\"");} 
    Serial.println("}");
  }

  if (spiBuffer[0] == 0x71)                                                                    // Base or Battery Event
  {
    Serial.print("{\"device\":\"");
    if (spiBuffer[1] <= 0x0F) {Serial.print("0");} Serial.print((spiBuffer[1]), HEX);
    if (spiBuffer[2] <= 0x0F) {Serial.print("0");} Serial.print((spiBuffer[2]), HEX);
    if (spiBuffer[3] <= 0x0F) {Serial.print("0");} Serial.print((spiBuffer[3]), HEX);
    Serial.print("\", \"model\":\"");
    if (spiBuffer[4] <= 0x0F) {Serial.print("0");} Serial.print((spiBuffer[4]), HEX);
    if (spiBuffer[5] <= 0x0F) {Serial.print("0");} Serial.print((spiBuffer[5]), HEX);
    Serial.print("\", \"base\":\"");

    //byte testBit = 0x04
    if (spiBuffer[6] & 0x04) {Serial.print("ON");} else {Serial.print("OFF");}

    Serial.print("\", \"battery\":\"");
    if (spiBuffer[6] & 0x42) {Serial.print("LOW");} else {Serial.print("OK");}
   // 1 is always set
   // 4 is base on/off
   // 2 and 64 seem to flag a low battery
   
    Serial.println("\"}");
  }

  if (spiBuffer[0] == 0x50)                                                                     // Emergency Event
  {
    Serial.print("{\"device\":\"");
    if (spiBuffer[1] <= 0x0F) {Serial.print("0");} Serial.print((spiBuffer[1]), HEX);
    if (spiBuffer[2] <= 0x0F) {Serial.print("0");} Serial.print((spiBuffer[2]), HEX);
    if (spiBuffer[3] <= 0x0F) {Serial.print("0");} Serial.print((spiBuffer[3]), HEX);
    Serial.print("\", \"event\":\"");
    if (spiBuffer[4] == 0x81) {Serial.print("FIRE ");}
    if (spiBuffer[4] == 0x41) {Serial.print("CARBON MONOXIDE ");}
    Serial.println("EMERGENCY\", \"base\":\"ON\"}");
  }

  if (spiBuffer[0] == 0x61)                                                                       // Silence Event
  {
    Serial.print("{\"device\":\"");
    if (spiBuffer[1] <= 0x0F) {Serial.print("0");} Serial.print((spiBuffer[1]), HEX);
    if (spiBuffer[2] <= 0x0F) {Serial.print("0");} Serial.print((spiBuffer[2]), HEX);
    if (spiBuffer[3] <= 0x0F) {Serial.print("0");} Serial.print((spiBuffer[3]), HEX);
    Serial.println("\", \"event\":\"SILENCE\", \"base\":\"ON\"}");
  }

  if (spiBuffer[0] == 0xD2)                                                                       // Missing Device Event
  {
    Serial.print("{\"device\":\"");
    if (spiBuffer[6] <= 0x0F) {Serial.print("0");} Serial.print((spiBuffer[6]), HEX);
    if (spiBuffer[7] <= 0x0F) {Serial.print("0");} Serial.print((spiBuffer[7]), HEX);
    if (spiBuffer[8] <= 0x0F) {Serial.print("0");} Serial.print((spiBuffer[8]), HEX);
    Serial.println("\", \"event\":\"MISSING\", \"base\":\"MISSING\", \"battery\":\"MISSING\"}");
  }
  
}



void processHeartBeat()
{
   if (directMode == false) {
  unsigned long currentRunTime = millis();
  if (currentRunTime - lastHeartBeat >= heartBeatInterval) 
  {
     Serial.print("{\"heartBeat\":\"");
     //Serial.print(millis()/heartBeatInterval);
     Serial.print(heartBeatValue);
     Serial.println("\"}");
     lastHeartBeat = currentRunTime;
    if (heartBeatValue < 9){heartBeatValue++;}
    else {heartBeatValue= 0;}
    }
   }
}



void loop()
{
  ReadByteFromRadio();                                      // check for incoming SPI byte from Radio to SPIbuffer (SPI master)
  if (radioReceiveBufferReady == true)
  { // write bytes from SPIbuffer to Serial
    if (directMode == true) {
      Serial.write(spiBuffer, spiBufferIndex);
    }
    else
    {
      processRadioResponse();                                //process the response
    }
    flushSPIbuffer();
  }
  checkIfSPIbufferIsStagnant();                             // check if incoming SPI data is incomplete
  ReadByteFromSerial();                                     // read serial buffer and send it to the radio when its ready
  processHeartBeat();
}

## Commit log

2022-01-20 enclosure update
    [WiSafe2-to-HA-Bridge-enclosure.stl]
2022-01-24 added hole to radio-button to enclosure lid
    [WiSafe2-to-HA-Bridge-enclosure.stl]
2022-02-15 arduino debug sketch upload
